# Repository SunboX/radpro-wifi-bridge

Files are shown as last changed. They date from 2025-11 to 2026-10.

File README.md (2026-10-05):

# RadPro WiFi Bridge (ESP32-S3)

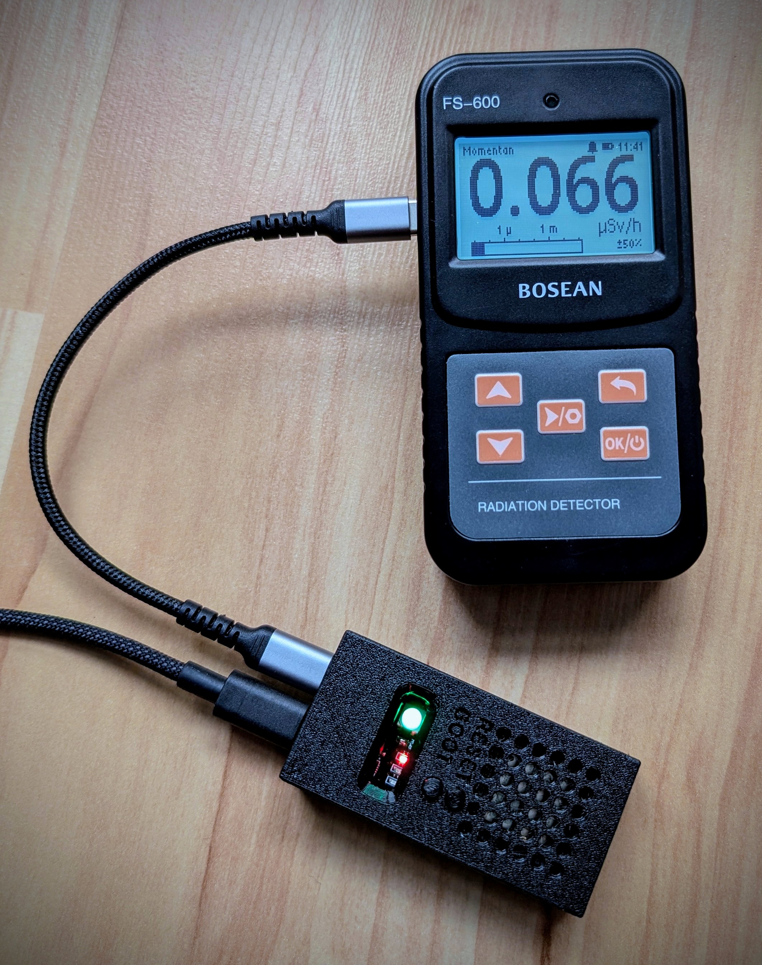
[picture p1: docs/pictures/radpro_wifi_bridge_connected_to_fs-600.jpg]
RadPro WiFi Bridge


Wi-Fi/USB bridge firmware for **Rad Pro class** Geiger counters, built on the excellent open-source Rad Pro firmware from https://github.com/Gissio/radpro.  
The ESP32-S3 enumerates the detector as a vendor-specific CDC device, provides status over the debug UART, keeps a heartbeat on the on-board WS2812, and mirrors telemetry to MQTT plus supported open-data services. Configuration is handled through a captive portal that stays available as a normal web UI once the device is on the network.

**Compatibility note:** Tested with **Bosean FS‑600**, **FNIRSI GC‑01** running firmware **“Rad Pro 3.0.1”** and **“Rad Pro 3.1test17”**, and **FNIRSI GC‑03** running firmware **“Rad Pro 3.1test17”**. Recent GC‑01 units that enumerate as standard STM32 CDC devices are supported as well. If you encounter problems with other adapters, please open an issue so we can track it. I’m happy to help, but I can’t afford to buy every device — get in touch if you’re able to loan or sponsor hardware for debugging.

**Tested Geiger counters**

-   FNIRSI GC-01
-   FNIRSI GC-03
-   Bosean FS-600
-   Bosean FS-5000 (tested by @wern0r)

**Not yet tested**

-   FS2011
-   YT-203B
-   Bosean FS-1000
-   JOY-IT JT-RAD01
-   GQ GMC-800

---

## Highlights

-   **TinyUSB host stack** with a CH34x VCP shim so the RadPro enumerates reliably on the ESP32-S3 OTG port.
-   **DeviceManager command queue** that boots the tube, logs identity/metadata, and keeps issuing telemetry `GET` commands.
-   **Wi-Fi configuration portal** (WiFiManager based) that launches an AP when credentials fail, serves the same form at `http://<device-ip>/`, and persists settings to NVS. A one-click “Restart Device” action is exposed in the UI.
-   **Runtime Wi-Fi diagnostics & startup control**: countdown-driven boot with serial overrides, plus SSID/IP/RSSI logging after the main firmware starts.
-   **MQTT publisher** with templated topics. Every successful RadPro response is forwarded at the configured `readIntervalMs`; publish success/failure drives LED pulses and console messages.
-   **Cloud publishers** for MQTT, OpenSenseMap, OpenRadiation, GMCMap, and Radmon.org with per-service toggles in the web portal.
-   **Home Assistant discovery** payloads so MQTT entities appear automatically once the bridge is online.
-   **Prometheus metrics** at `/metrics` for radiation and battery readings, with device information labels. See [docs/prometheus.md](docs/prometheus.md) for scrape configuration and metric details.
-   **OTA bridge firmware updates** via the web portal (or browser-based ESP Web Tools installer) so you can stay current without reflashing over USB.
-   **RGB LED state machine** (WS2812 on GPIO 48) that communicates boot, Wi-Fi, USB, and error states without needing the serial console.

---

## Hardware Assembly

Need help soldering the ESP32-S3 jumpers or printing the enclosure? Follow the step-by-step guide in [docs/assembly.md](docs/assembly.md). If you are sourcing your own board, see [docs/board-requirements.md](docs/board-requirements.md) for the recommended model and the minimum requirements for the default build.

---

## Board Requirements

The default setup now targets **ESP32-S3-DevKitC-1-N16R8**. The discontinued
**ESP32-S3-DevKitC-1-N16R8V** remains compatible, but it is no longer treated as
the only valid choice.

- **Recommended board:** `ESP32-S3-DevKitC-1-N16R8` (16 MB flash, 8 MB PSRAM, two USB ports, onboard WS2812).
- **Default build requirement:** `16 MB` flash, because the repository ships a dual-OTA layout plus a `2 MB` LittleFS partition.
- **Current firmware requirement:** PSRAM is optional for the current source tree; the default firmware builds without enabling PSRAM-specific support.

See [docs/board-requirements.md](docs/board-requirements.md) if you want to compare alternative boards or port the firmware to a smaller flash layout.

---

## Web Installer (ESP Web Tools)

Flash the bridge firmware straight from your browser: https://SunboX.github.io/radpro-wifi-bridge/web-install/ (v1.15.14)

Connect the ESP32-S3 via USB, click **Install**, and follow the prompts—no local toolchain required. OTA updates of the bridge firmware are also available from the web portal once a network connection is active.

---

## PlatformIO Install

1. Install [PlatformIO](https://platformio.org/) and open this project.
2. The default environment targets the project-local **ESP32-S3 DevKitC-1 (N16R8)** profile with TinyUSB host support (`platformio.ini`) and a custom `partitions.csv` that provides two OTA slots plus a `2 MB` LittleFS partition on `16 MB` flash.
3. Connect the board with **two** USB cables:
    - CP210x (UART) port → logs & commands (`Serial0`, 115200 baud).
    - Native USB-OTG port → leave free for the RadPro sensor.
4. Flash with `platformio run --target upload` (or `--target upload --target monitor` to auto-open the serial monitor).

---

## First Boot & Portal

1. Watch the countdown on the UART. Enter `start` to skip the delay or adjust it with `delay <ms>`.
2. On first boot— or whenever stored credentials fail— the firmware hosts a captive portal named `<device name> Setup`. After Wi-Fi joins successfully the same configuration UI is served at `http://<device-ip>/`.

---

## Wi-Fi Configuration Portal

`WiFiPortalService` keeps the setup UI reachable whether the bridge is broadcasting a captive portal (`<deviceName> Setup`) or already joined to your LAN (`http://<device-ip>/`). Use it to edit Wi-Fi credentials, toggle MQTT/OpenSenseMap/OpenRadiation/Safecast/GMCMap/Radmon publishers, or trigger a remote restart (`/restart`). All changes are persisted to NVS immediately and the console logs SSID/IP/RSSI updates for quick troubleshooting.

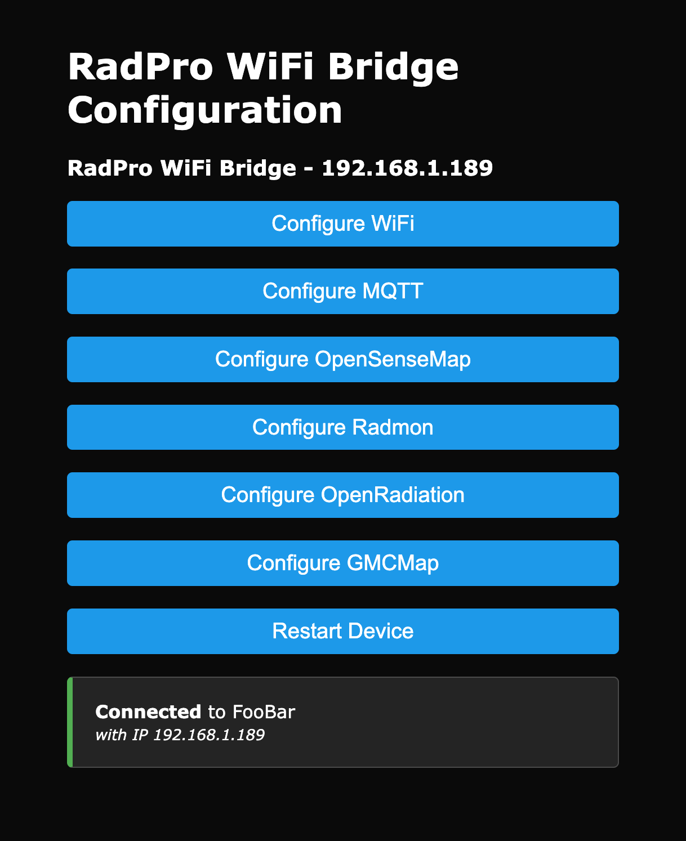
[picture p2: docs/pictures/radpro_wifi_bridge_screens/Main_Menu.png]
Wi-Fi portal Main Menu


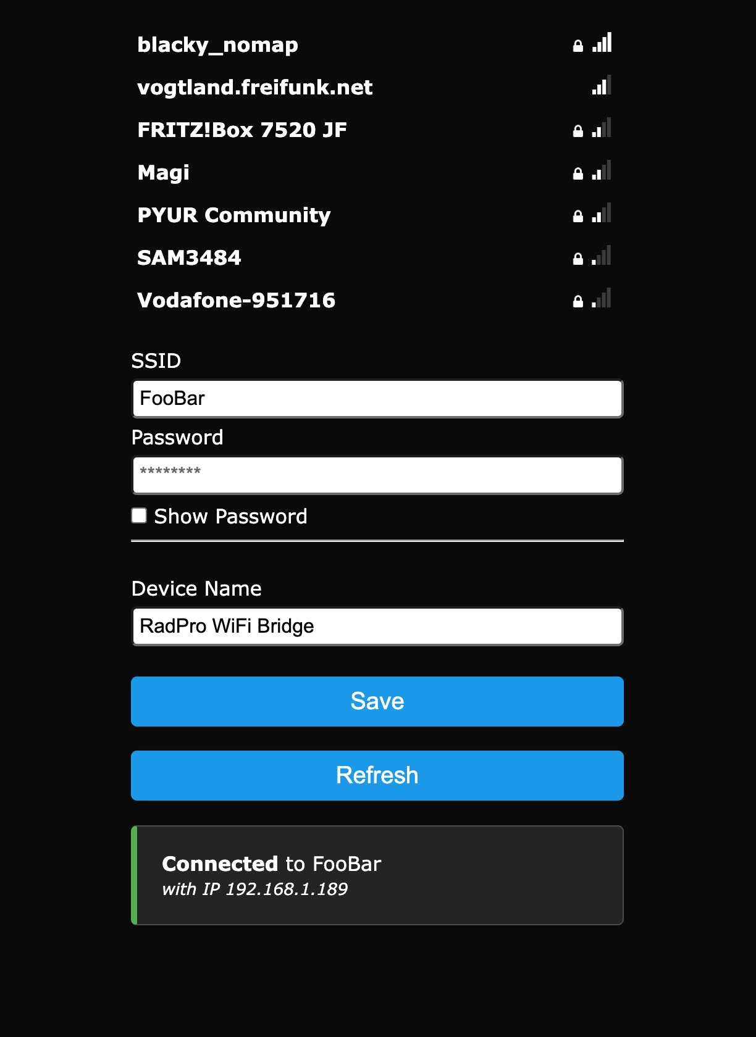
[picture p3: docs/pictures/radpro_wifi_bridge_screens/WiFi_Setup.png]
Wi-Fi setup form


---

## MQTT Publishing

Need a step-by-step walkthrough? See [docs/mqtt-home-assistant.md](docs/mqtt-home-assistant.md) for detailed MQTT broker setup and Home Assistant discovery notes.

The `MqttPublisher` mirrors every RadPro response to MQTT once you enable it in the portal. Topics are templated (`stat/radpro/<deviceid>/<leaf>` by default), retained, and paired with Home Assistant discovery payloads so entities appear automatically. Successful publishes pulse the LED green while the bridge is not in error mode; routine broker outages stay in the console so the bridge can keep showing its healthy USB/Wi-Fi state on the LED. Authentication, configuration, or telemetry alarm states still keep priority on the LED.

---

## OpenSenseMap Publishing

For screenshots and a full walkthrough see [docs/opensensemap.md](docs/opensensemap.md).

Toggle the feature on via **Configure OpenSenseMap**, paste in your box/token/sensor IDs, and the bridge will bundle tube rate + dose rate readings into HTTPS posts every few seconds. Nothing is transmitted while the toggle is off or IDs are blank.

---

## OpenRadiation Publishing

For the setup flow and field-by-field notes see [docs/openradiation.md](docs/openradiation.md).

Enable **Configure OpenRadiation**, enter your API key plus OpenRadiation user ID/password, and fill in the station location metadata used by the OpenRadiation API. The bridge can reuse the connected detector's device ID automatically when the optional apparatus ID is left blank, and the page exposes direct links to the public OpenRadiation map, a redacted dry-run payload preview, and the latest successfully published measurement.

---

## Safecast Publishing

For the full Safecast setup flow and troubleshooting notes see [docs/safecast.md](docs/safecast.md).

Enable **Safecast konfigurieren**, enter your Safecast API key and station coordinates, choose `cpm` or `µSv/h`, and set the upload interval. The bridge posts averaged direct measurements to Safecast, supports one-shot test uploads from the portal, masks the saved API key in the UI, and includes a checkbox plus custom endpoint override for running against a test system instead of production.

---

## GMCMap Publishing

Need screenshots and credentials pointers? See [docs/gmcmap.md](docs/gmcmap.md).

Enable GMCMap support, enter your Account ID/Device ID, and the bridge posts CPM + µSv/h pairs to `log2.asp` roughly once per minute. Leave it disabled if you don’t use GMCMap—no traffic is generated unless credentials are populated.

---

## Radmon Publishing

For screenshots and the full walk-through see [docs/radmon.md](docs/radmon.md).

Enable the Radmon toggle, enter your station username plus data-sending password, and the bridge submits CPM (and µSv/h when available) once per minute. Disable the feature if you don’t use radmon.org; no HTTP requests are made until valid credentials exist.

---

## LED Feedback

Base modes communicate long-running state (default brightness is gentle to avoid glare):

| Mode | Pattern / Colour | Meaning |
| --- | --- | --- |
| `Booting` | Magenta blink (~0.4 s period) | Firmware initialising before the countdown runs. |
| `WaitingForStart` | Yellow blink (~0.6 s period)  | Startup delay active; awaiting timeout or `start` command. |
| `WifiConnecting`  | Blue blink (~0.6 s period) | Attempting to join the configured WLAN. |
| `WifiConnected` | Cyan steady | Wi-Fi joined; USB device not yet ready. |
| `DeviceReady` | Bright green steady | RadPro enumerated and telemetry queue active. |
| `Error` | Amber blink (~0.5 s period) | Device communication or telemetry activity failed; check the console for the current alarm. |

Event pulses temporarily override healthy base colours. Error mode and latched fault patterns keep priority so alarms are not masked:

-   **MQTT success:** bright green flash (~150 ms).
-   **Device command error:** bright red flash (~250 ms) and a console log (`Device command failed: <id>`).
-   **Routine MQTT disconnects:** logged to the console, but they no longer force the LED into the red/amber fault pattern while Wi‑Fi + USB + detector are otherwise healthy.

### Fault Blink Codes

Certain faults latch a repeating red/orange sequence so you can diagnose issues without watching the serial log. The pattern always starts with **one red blink**, followed by the number of **orange blinks** listed below; the sequence then pauses briefly and repeats.

| Code | Issue | LED pattern |
| ---- | --- | --- |
| 1 | NVS load failed (preferences missing) | red ×1 → orange ×1  |
| 2 | NVS write failed (configuration not saved) | red ×1 → orange ×2  |
| 3 | Wi‑Fi authentication / association error | red ×1 → orange ×3  |
| 4 | Wi‑Fi connected but no IP (DHCP/gateway) | red ×1 → orange ×4  |
| 5 | Captive/config portal still required | red ×1 → orange ×5  |
| 6 | MQTT broker unreachable / DNS failure | red ×1 → orange ×6  |
| 7 | MQTT authentication failure | red ×1 → orange ×7  |
| 8 | MQTT connection reset while publishing | red ×1 → orange ×8  |
| 9 | MQTT discovery payload exceeded buffer | red ×1 → orange ×9  |
| 10 | USB device disconnected / CDC error | red ×1 → orange ×10 |
| 11 | USB interface descriptor parse failure | red ×1 → orange ×11 |
| 12 | TinyUSB handshake unsupported | red ×1 → orange ×12 |
| 13 | `GET deviceId` timed out | red ×1 → orange ×13 |
| 14 | Command queue timeout / retries exhausted | red ×1 → orange ×14 |
| 15 | Tube sensitivity missing (dose rate unavailable) | red ×1 → orange ×15 |
| 16 | Wi‑Fi reconnect after config save still failing  | red ×1 → orange ×16 |
| 17 | Captive portal resource exhaustion | red ×1 → orange ×17 |
| 18 | LED controller stuck in Wi‑Fi mode | red ×1 → orange ×18 |
| 19 | Application image larger than partition | red ×1 → orange ×19 |
| 20 | Upload attempted on wrong serial port | red ×1 → orange ×20 |
| 21 | Home Assistant using stale discovery state | red ×1 → orange ×21 |
| 22 | Home Assistant broker without retained discovery | red ×1 → orange ×22 |
| 23 | Last reset caused by brownout | red ×1 → orange ×23 |
| 24 | Last reset caused by watchdog | red ×1 → orange ×24 |

The lowest-numbered active fault is displayed. Resolving the root cause (for example, restoring Wi‑Fi credentials or saving NVS successfully) clears that code and reveals any higher-numbered faults that remain. Some codes are reserved for diagnostic scenarios outside normal runtime, but the blink language stays consistent if you raise them manually.

---

## Serial Console Commands (`Serial0`)

| Command | Description |
| --- | --- |
| `start` | Skip the remaining startup delay and begin immediately. |
| `delay <ms>` | Set a new startup delay (milliseconds) and restart the timer. |
| `raw on/off` | Enable or disable raw USB frame logging. |
| `raw toggle` | Toggle raw USB logging. |

While waiting for the boot delay the console prints `Starting in …` once per second. After the bridge starts, only device data, Wi-Fi status changes, and MQTT diagnostics are logged— the old “Main loop is running.” chatter is gone.

Raw USB logging is invaluable when reverse-engineering RadPro responses; disable it once finished to minimise serial traffic.

---

## Device Telemetry Flow

1. **USB enumeration** uses TinyUSB with a CH34x fallback so the RadPro reliably appears as a CDC device.
2. **Handshake:** `GET deviceId` logs the raw ID, model, firmware, and locale. Additional metadata (`devicePower`, `deviceBatteryVoltage`, `deviceTime`, `tube` parameters) is fetched immediately afterwards.
3. **Continuous polling:** `GET devicePower`, `GET tubePulseCount`, and `GET tubeRate` are queued at the configured interval (`readIntervalMs`, clamped to ≥ 500 ms).
4. **Activity guard:** `devicePower=0`, repeated telemetry timeouts after live data was seen, or a tube pulse counter that stops advancing raises an amber telemetry alarm, clears pending measurement uploads, and suppresses stale tube readings until the detector reports live data again.
5. **MQTT forwarding:** each healthy successful response is offered to the MQTT publisher; failures propagate to the LED and console.
6. **Optional diagnostics:** enable raw USB logging for byte-level traces or request `randomData` / `dataLog` from higher-level code to stream ad-hoc payloads.

Retries, back-off, and duplicate suppression are handled inside `DeviceManager`.

---

## Project Structure

| Path | Purpose |
| --- | --- |
| `src/main.cpp` | Arduino entry point: startup sequencing, Wi-Fi orchestration, LED updates, telemetry loop. |
| `components/usb_host_vcp` | ESP-IDF component that wraps TinyUSB + vendor CH34x handling so the RadPro enumerates reliably. |
| `lib/UsbCdcHost` | High-level USB CDC host wrapper used by `DeviceManager`. |
| `lib/DeviceManager` | Command queue, response parsing, retries/back-off, publish callbacks. |
| `lib/AppSupport/*` | Support modules (AppConfig, ConfigPortal, Mqtt, Led, diagnostics helpers). |
| `docs/assembly.md` | Hardware assembly guide (solder bridges, enclosure, flashing). |
| `docs/mqtt-home-assistant.md` | Detailed MQTT/Home Assistant setup guide. |
| `docs/opensensemap.md`, `docs/openradiation.md`, `docs/safecast.md`, `docs/gmcmap.md`, `docs/radmon.md` | Service-specific publishing guides and setup notes. |
| `docs/web-install/` | Browser-based installer (ESP Web Tools) plus staged firmware bundle (`firmware/latest`). |
| `tools/copy_firmware.py` | PlatformIO post-build hook that refreshes the `docs/web-install/firmware/latest/` artifacts. |
| `platformio.ini` | PlatformIO configuration targeting the ESP32-S3 DevKitC-1 with TinyUSB host support. |

---

## Roadmap

-   Add configurable reporting thresholds / batching beyond the global interval.
-   OTA firmware update of the connected Rad Pro device (bridge already updates itself OTA via the portal).
-   Investigate additional publisher targets:
    -   **uRADMonitor** – global network with proprietary + DIY kits; includes API protocols for feeding third-party data once a device is registered.
    -   **GammaSense** – Waag/RIVM citizen sensing initiative; API access may require project partnership depending on phase/status.

---

## License

This project is available under two licensing options:

### 1. Open-source license

GNU General Public License v3.0 or later (`GPL-3.0-or-later`).

You may use, modify, and distribute this project under the GPL. If you distribute modified versions or larger works based on this project, they must comply with the GPL, including source-code availability requirements.

Documentation, tutorials, diagrams, screenshots, and non-code media are licensed under Creative Commons Attribution-ShareAlike 4.0 (`CC-BY-SA-4.0`) unless otherwise marked.

Case and hardware design files are licensed under the CERN Open Hardware Licence Version 2 - Strongly Reciprocal (`CERN-OHL-S-2.0`) unless otherwise marked.

### 2. Commercial/proprietary license

For use in closed-source, proprietary, or otherwise GPL-incompatible products, a separate commercial license is required.

Commercial licensing contact: **mail@andrefiedler.de**

### Attribution / notices

Copyright (C) 2026 André Fiedler.

Original source: https://github.com/SunboX/radpro-wifi-bridge

Copyright, license, attribution, and source-origin notices must be preserved as required by the GPL and the notice files in this repository.

Bundled third-party components keep their own licenses. See the license files and SPDX metadata within `components/` and `data/portal/js/jszip.min.js` for those terms.

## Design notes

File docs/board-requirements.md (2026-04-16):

# Board Requirements

This project no longer depends on the discontinued
`ESP32-S3-DevKitC-1-N16R8V`. The default PlatformIO profile now targets the
currently common `ESP32-S3-DevKitC-1-N16R8`, and the same firmware layout also
fits `N16R8V` boards.

## Recommended Board

- `ESP32-S3-DevKitC-1-N16R8`
- `16 MB` flash
- `8 MB` PSRAM
- two USB connectors so you can keep the OTG port free for the detector and use
  the second port for flashing/logs
- onboard WS2812 on `GPIO48`

## Minimum Requirements For The Default Build

If you want to compile this repository without changing the partition layout,
your board should provide:

- an `ESP32-S3` with native USB OTG host support
- routing that allows the OTG port to connect to the detector after the
  documented solder bridges are closed
- `16 MB` flash
- a way to flash firmware and read logs while the detector uses the OTG port
  (a second USB/UART path is the easiest option)

## What Is Optional

- PSRAM is currently optional for this firmware. The current codebase builds and
  links without enabling PSRAM-specific support.
- An onboard WS2812 is recommended because the firmware uses it for status, but
  you can adapt the LED wiring if your board exposes a different RGB LED or no
  LED at all.
- The exact DevKitC module suffix is not critical as long as the board meets the
  flash, USB-OTG, and routing requirements.

## If You Want To Use A Smaller Board

Boards with less than `16 MB` flash are not supported by the default layout.
The repository currently reserves:

- two OTA application slots (`ota_0`, `ota_1`)
- a `2 MB` LittleFS partition for the web portal assets

If you want to target an `8 MB` or smaller board, you need to provide your own:

- smaller partition table
- reduced OTA strategy or a single-app layout
- matching web installer offsets if you also want to keep browser flashing

That is possible, but it is a separate board-porting task rather than the
default configuration.

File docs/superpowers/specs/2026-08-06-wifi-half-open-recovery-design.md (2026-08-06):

# Wi-Fi Half-Open Recovery Design

Date: 2026-08-06
Branch: `main`
Target release: `1.15.13`

## Goal

Fix both Wi-Fi recovery failures reported in GitHub issue #21:

- stop the bridge reconnect loop from interrupting a successful station association before DHCP supplies an IP address
- recover when the ESP32 still reports `WL_CONNECTED` although the local Wi-Fi data path is no longer usable

The release will be built and verified locally, but it will be published without a physical-device test because the maintainer is on holiday and currently has no access to the bridge hardware.

## Investigation Summary

The issue contains two distinct failure sequences.

### Rapid reconnect loop

Arduino-ESP32 2.0.17 enables its own automatic reconnect by default. Release 1.15.12 also added an application-level reconnect loop. The bridge sets `pendingReconnect_` on every `STA_DISCONNECTED` event and resets the retry timestamp to zero. After `STA_CONNECTED`, Arduino does not report `WL_CONNECTED` until `GOT_IP`; during that interval the bridge can call `WiFi.reconnect()` again and tear down the association before DHCP completes. The resulting disconnect event resets the retry delay, causing another immediate attempt.

### Beacon-timeout half-open connection

The follow-up log contains `wifi:bcn_timeout,ap_probe_send_start`, followed by repeated MQTT TCP timeouts, but no `STA_DISCONNECTED` event. Espressif documents the beacon timeout as an intermediate state: the station sends probe requests and only disconnects when those probes also fail. In the reported case Arduino continued returning `WL_CONNECTED`, which is also demonstrated by the MQTT publisher proceeding past its Wi-Fi status guard.

The bridge currently arms recovery only after `STA_DISCONNECTED`. It has no independent reachability check, so a stale association can remain offline indefinitely.

The log cannot determine why the original beacons disappeared. Possible causes include RF conditions, temporary AP behavior, or an ESP-IDF 4.4.7 driver state problem. The firmware fix therefore targets reliable recovery rather than claiming to eliminate the initiating radio event.

## Considered Approaches

### 1. Gateway ICMP reachability monitor with a proven-good baseline

Periodically send one asynchronous ICMP echo to the configured gateway. Do not enforce failures until the gateway has answered successfully at least once for the current IP lease. After three consecutive failures, explicitly tear down the stale station connection and hand control to the bridge reconnect state machine.

Advantages:

- tests the local Wi-Fi path independently of MQTT or any internet service
- does not reconnect merely because a configured publisher is unavailable
- the successful-baseline requirement avoids breaking installations whose routers intentionally ignore ICMP

Trade-off:

- recovery begins after a conservative detection window rather than after the first failed packet

### 2. Treat repeated MQTT failures as Wi-Fi failures

This is simpler, but it conflates broker availability, DNS, authentication, and Wi-Fi health. A broker outage could force needless Wi-Fi reconnects, and installations with MQTT disabled would have no watchdog.

### 3. Reboot after prolonged publisher failure

This provides a broad escape hatch but loses diagnostic state, interrupts USB/device processing, and still cannot distinguish a network outage from an application-service outage.

## Selected Approach

Use approach 1 and make the bridge the sole owner of reconnect timing.

- disable Arduino's automatic reconnect after Wi-Fi setup so the Arduino layer and bridge do not issue competing connection commands
- suppress application reconnect attempts while association is waiting for `GOT_IP`
- preserve the retry timestamp across repeated disconnect callbacks instead of making every callback immediately due
- clear reconnect state explicitly on `GOT_IP`
- monitor the gateway with asynchronous, single-packet ICMP probes
- require one successful gateway probe before enforcing failures for the current IP lease
- recover after three consecutive failed probes

## Detailed Design

### Reconnect state policy

Extend the existing host-testable Wi-Fi reconnect policy with pure decisions for:

- whether a reconnect attempt must wait while DHCP is in progress
- whether a new disconnect should make the first retry immediately due or preserve an already-running retry interval
- when a gateway failure streak becomes actionable

Runtime behavior:

1. `STA_DISCONNECTED` arms reconnect immediately only when reconnect was not already pending.
2. `STA_CONNECTED` records the start of the DHCP wait and prevents another reconnect attempt.
3. `GOT_IP` clears `pendingReconnect_`, the retry timestamp, and the DHCP wait.
4. If `GOT_IP` does not arrive within ten seconds, DHCP waiting expires and the normal five-second reconnect policy resumes.
5. Arduino auto-reconnect is disabled so only this state machine issues reconnect requests.

### Gateway health policy

Add a small host-testable policy object with these states:

- `unproven`: no successful gateway response has been observed for the current lease
- `healthy`: at least one response has been observed and the failure streak is zero
- `suspect`: the gateway was previously proven reachable and one or two consecutive probes failed
- `stale`: the gateway was previously proven reachable and three consecutive probes failed

Rules:

- a success proves the gateway and resets the failure streak
- failures before the first success are diagnostic only and never force recovery
- three consecutive failures after a success request stale-link recovery
- a new IP lease resets the policy to `unproven`
- any Wi-Fi disconnect cancels enforcement until a new `GOT_IP`

### Gateway probe runtime

Use ESP-IDF's asynchronous `esp_ping` session API:

- target: `WiFi.gatewayIP()`
- packet count: one
- timeout: 1000 ms
- interval between probes: 30 seconds
- no blocking work in the Arduino loop

The ping callbacks only record completion and success. The main loop consumes the result, updates the pure policy, and performs all logging and Wi-Fi state changes.

If the ping session cannot be created or started, log the ESP error and retry at the next interval. Session-setup errors do not count as gateway failures.

When the policy reports a stale link:

1. log the failure count and gateway address
2. stop treating the cached `WL_CONNECTED` value as healthy
3. arm bridge reconnect state
4. explicitly disconnect the station without erasing saved credentials
5. let the normal reconnect policy rejoin the saved network

### Logging and diagnostics

Add concise state-transition logs rather than one line for every successful periodic probe:

- gateway monitor armed after its first successful probe
- gateway probe failure count while armed
- stale link detected and forced recovery started
- DHCP wait timed out
- ping session creation/start failure with the ESP error name

Successful probes after the baseline remain silent unless they recover a prior failure streak.

## Error Handling and Safety

- Router does not answer ICMP: the monitor never gets a successful baseline and therefore never forces recovery.
- Gateway address is zero or unavailable: skip probing until a valid `GOT_IP` event supplies one.
- Ping allocation/socket failure: log and retry later; do not classify the link as stale.
- Wi-Fi disconnect during a probe: ignore the completed result for health enforcement and reset on the next IP lease.
- DHCP is slow: wait up to ten seconds before allowing another reconnect command.
- Gateway recovers after one or two missed probes: reset the failure streak without disconnecting Wi-Fi.
- Persistent gateway failure after a proven-good baseline: force one disconnect, reset health state, and rely on the existing bounded reconnect interval.
- Saved credentials remain intact throughout recovery.

## Testing

Follow a red-green test cycle before implementation.

Host regression tests will cover:

- reconnect is suppressed between `STA_CONNECTED` and `GOT_IP`
- DHCP waiting expires after ten seconds
- repeated disconnect callbacks preserve an active retry delay
- `GOT_IP` clears pending reconnect state
- gateway failures before the first success never trigger recovery
- a success arms gateway enforcement
- one and two post-baseline failures remain non-actionable
- the third consecutive post-baseline failure triggers stale-link recovery
- a success resets a failure streak
- a new lease resets the successful baseline

Build verification will include:

- all repository host tests
- PlatformIO `buildprog`
- PlatformIO `buildfs`
- inspection of generated version metadata and the `firmware_1.15.13.zip` contents
- comparison of the committed source state with the generated firmware version string

Physical-device behavior will remain explicitly unverified for this release because no device is available during the maintainer's holiday.

## Release and Issue Communication

Release 1.15.13 will include:

- a detailed explanation of the two failure modes
- the gateway-monitor design and false-positive protection
- the reconnect/DHCP race correction
- local test and build evidence
- a clear statement that the release has not yet been tested on physical hardware

The GitHub issue reply will be written as a short, direct maintainer update in André's established style: thank the reporter, explain the investigation and fix in concrete terms, link the release, state that hardware testing was not possible while on holiday, and ask the reporter to test and share a log if possible.

## Non-Goals

- claiming the firmware can identify the original RF or access-point cause from the supplied log
- treating cloud-service or MQTT outages as Wi-Fi failures
- restarting the whole ESP32 as the first recovery action
- erasing or replacing stored Wi-Fi credentials
- upgrading the Arduino-ESP32 or ESP-IDF toolchain in the same release

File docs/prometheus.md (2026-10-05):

# Prometheus metrics

The bridge exposes its current detector readings at `http://<device-ip>/metrics`
on the same HTTP server as the web portal. Prometheus can scrape this endpoint
without MQTT or a separate exporter, and Grafana can display the stored readings
through a Prometheus data source.

Add a scrape job to `prometheus.yml`, replacing the example IP with your bridge:

```yaml
scrape_configs:
  - job_name: radpro
    scrape_interval: 15s
    static_configs:
      - targets: ["192.168.1.50:80"]
```

The default Prometheus metrics path is `/metrics`.

| Metric | Type | Unit / meaning |
| --- | --- | --- |
| `radpro_info` | Gauge | Constant `1`, with manufacturer, model, detector firmware, bridge firmware, device ID, locale and device power labels |
| `radpro_tube_rate` | Gauge | Counts per minute |
| `radpro_tube_dose_rate` | Gauge | Microsieverts per hour |
| `radpro_tube_pulse_count` | Counter | Detector pulse count; can reset when the detector resets |
| `radpro_battery_voltage` | Gauge | Volts |
| `radpro_battery_percent` | Gauge | Battery percentage estimated by the bridge from battery voltage |

The endpoint exports the latest readings already collected by the bridge.
Scraping it does not trigger a detector read. Unavailable readings are omitted,
including during startup, after USB disconnect, or while measurements are
cleared because the detector is off or stale. A missing sensitivity may leave
the dose-rate metric unavailable while CPM remains available. Actual zero
readings are exported as zero.

Device labels support UTF-8. Backslashes, double quotes and line feeds are escaped
according to the Prometheus text format.

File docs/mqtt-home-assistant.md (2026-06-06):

# MQTT & Home Assistant Integration

This guide walks through configuring the RadPro WiFi Bridge to publish RadPro telemetry over MQTT and explains how Home Assistant automatically discovers the exposed entities.

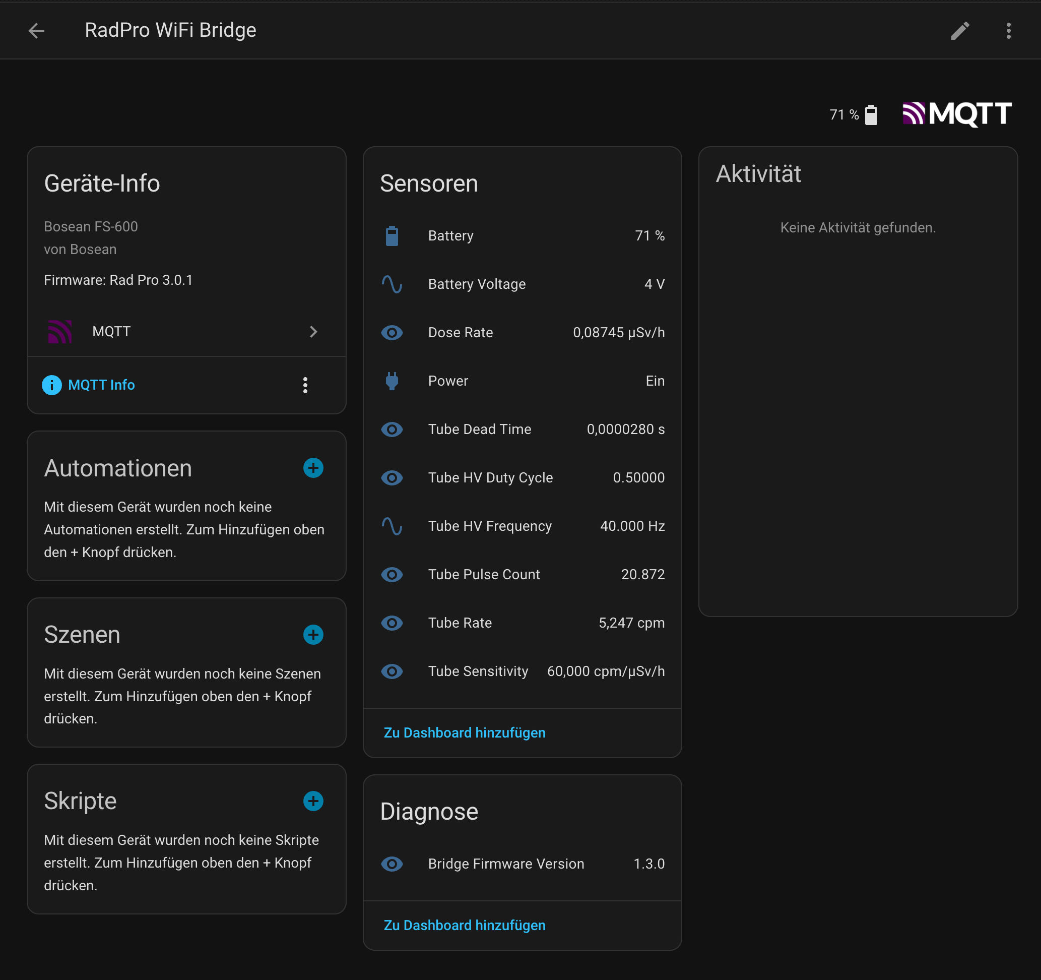
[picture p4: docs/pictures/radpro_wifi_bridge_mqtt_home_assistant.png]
RadPro WiFi Bridge sensors rendered inside Home Assistant


## 1. Prepare Your MQTT Broker

1. Run an MQTT broker such as Mosquitto (Home Assistant add-on or stand-alone).
2. Create a dedicated MQTT user/password, or enable anonymous access:
   - **Home Assistant add-on:** set `anonymous: true` under the add-on options, *or* add a user in Home Assistant and grant MQTT access.
3. Note the broker host/IP and port (default 1883).

> **Tip:** A `MQTT connect failed: 5` log on the bridge means the broker rejected the credentials. `MQTT connect failed: -1` or `-2` usually means the bridge cannot open the TCP connection to the broker.

## 2. Configure MQTT in the Portal

1. Power the bridge and connect via Wi-Fi/Captive portal.
2. Open **Configure MQTT**:
   - Toggle **Enable MQTT publishing**.
   - Fill in host, port, client ID suffix, username/password.
   - Adjust the base topic (`mqttTopic`) and full topic template (`mqttFullTopic`) if you want to customise the namespace. Defaults yield `stat/radpro/<deviceid>/<leaf>`.
   - Set the RadPro polling interval (`readIntervalMs`, minimum 500 ms).
3. Save to write the settings to NVS; the bridge will reconnect with the new details.

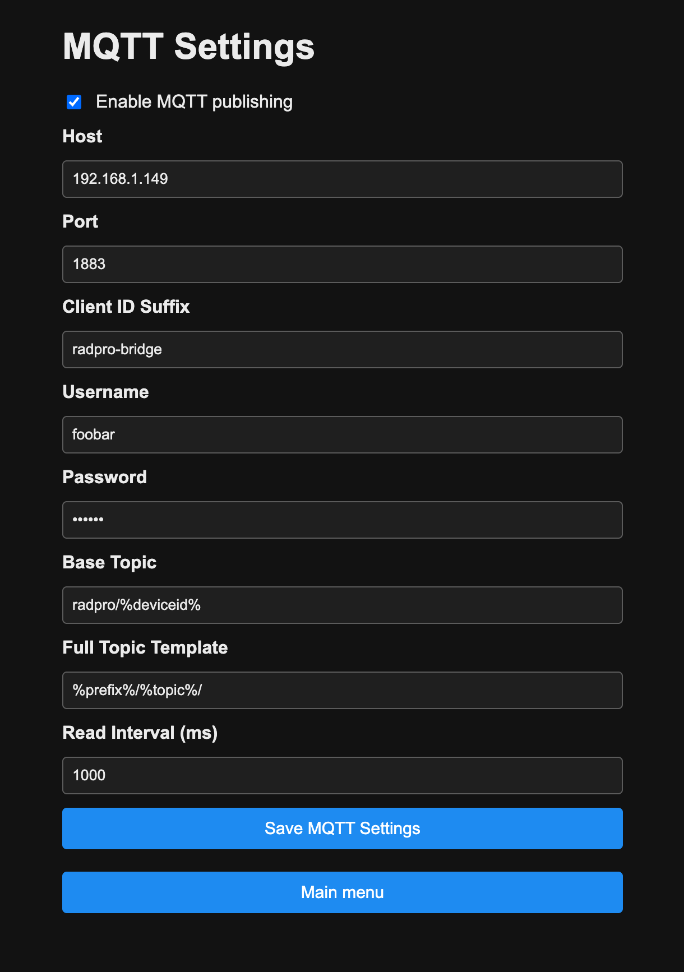
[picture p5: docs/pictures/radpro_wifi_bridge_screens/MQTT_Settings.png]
MQTT configuration page


## 3. Published Topics

Once connected, every RadPro response is forwarded to MQTT. The bridge publishes (retained) leaves such as:

- `bridgeVersion`, `deviceId`, `devicePower`
- `deviceBatteryVoltage`, `deviceBatteryPercent`
- `tubePulseCount`, `tubeRate`, `tubeDoseRate`, `tubeDeadTime`, `tubeDeadTimeCompensation`
- `tubeHvFrequency`, `tubeHvDutyCycle`
- Diagnostic entries like `randomData` or `dataLog` (not retained)

Topic templating variables:

- `%deviceid%` → lower-case slug of the RadPro device ID.
- `%DeviceId%` → exact device ID.
- `%prefix%` and `%topic%` → inserted into the full topic template to build the final MQTT topic string.

## 4. Home Assistant Discovery

As soon as the bridge learns the RadPro device ID it emits MQTT Discovery payloads under `homeassistant/<component>/<unique_id>/config`. Home Assistant automatically creates entities for:

- Tube rate (cpm) sensor
- Tube dose-rate sensor
- Pulse count
- Battery voltage & percentage
- Device power state
- Bridge firmware/diagnostics

Entities update in place whenever you rename the device in the portal or change topics. To ensure Home Assistant keeps the discovery data:

- Keep MQTT retain enabled (default behaviour on the bridge).
- If you purge retained messages manually, restart the bridge afterward to republish discovery payloads.

### Fixing Missing Entities

If Home Assistant doesn’t show the entities:

1. Confirm the bridge is publishing to the broker (`mosquitto_sub -v -t 'homeassistant/#'`).
2. Ensure the Home Assistant broker has `retain` enabled and that discovery is turned on (`mqtt:` in `configuration.yaml`).
3. Clear stale discovery topics:
   - Delete `homeassistant/radpro_*` retained topics (e.g. via MQTT Explorer).
   - Restart the bridge so it re-sends discovery payloads.

## 5. Using the Data

Once entities appear, you can:

- Display tube rate / dose rate in Lovelace dashboards.
- Trigger automations (e.g., notification if dose rate exceeds a threshold).
- Record long-term statistics using Home Assistant’s Recorder/History.

## Troubleshooting Checklist

| Symptom | Fix |
| --- | --- |
| `MQTT connect failed: -1` or `-2` | Broker unreachable (check host, port, Wi-Fi, firewall rules, VLAN/routing, and Home Assistant add-on network access) |
| `MQTT connect failed: 5` | Bad username/password or anonymous disabled |
| Entities missing after rename | Clear retained `homeassistant/` topics and restart bridge |
| State updates delayed | Lower `readIntervalMs` (>= 500 ms) and ensure broker isn’t rate-limited |

If a desktop MQTT client can connect but the bridge still logs `-1` or `-2`, test from the same Wi-Fi/VLAN as the bridge and check that no firewall rule blocks traffic from the bridge IP to the broker port.

For more detail on the firmware internals, see the “MQTT Publishing” section in the root README.

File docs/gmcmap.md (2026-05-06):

# GMCMap Publishing

This guide explains how to configure the RadPro WiFi Bridge to submit readings to [GMCMap](https://www.gmcmap.com/).

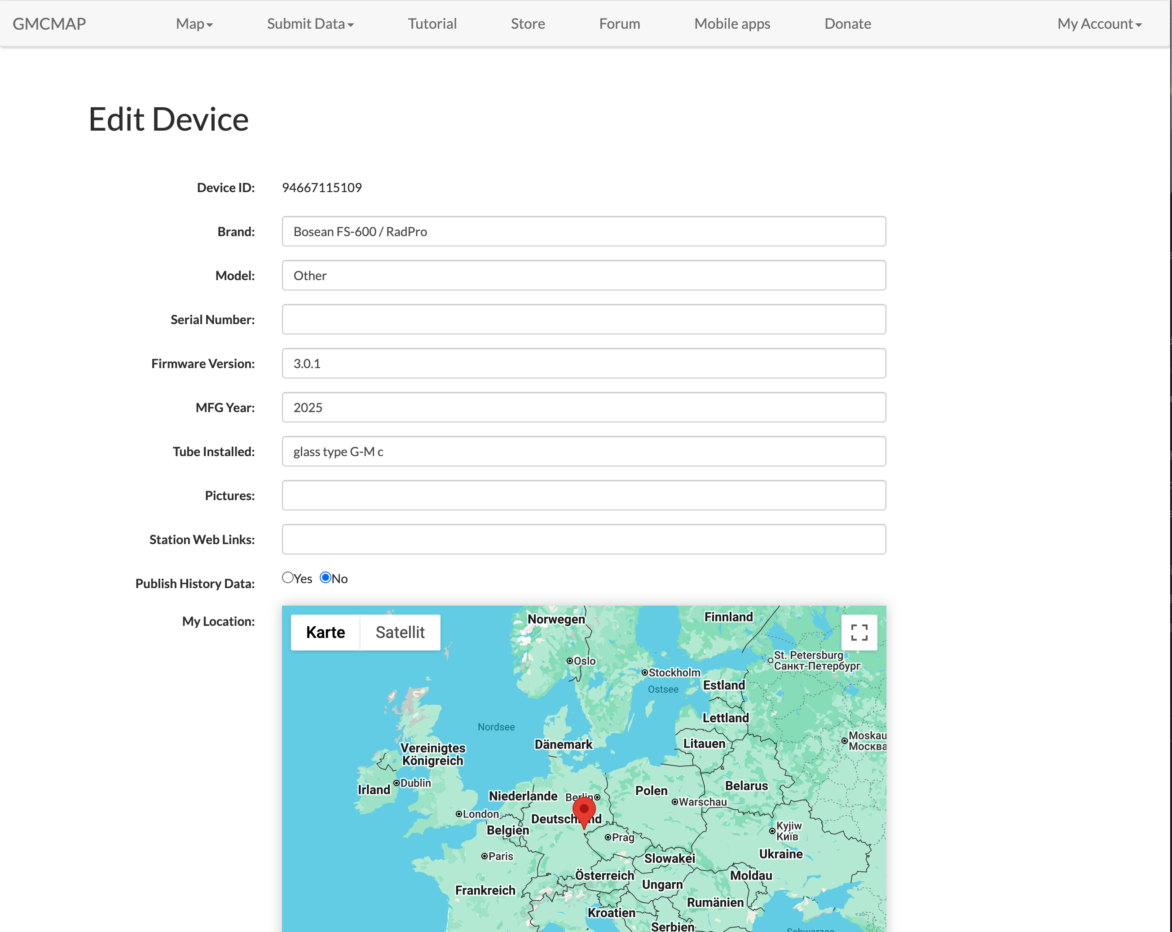
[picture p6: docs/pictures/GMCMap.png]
GMCMap dashboard with RadPro WiFi Bridge device


## 1. Get Your GMCMap Credentials

1. Log in to GMCMap and open **My Account** → **My Geiger Counter**.
2. For the device you want to feed with the bridge, note:
   - **Account ID** (a numeric identifier).
   - **Device ID** (also numeric, unique per counter).
   - Optional **Password** (only if you set one—leave blank otherwise).

These values appear on the device details page and are needed in the bridge portal.

## 2. Configure the RadPro WiFi Bridge

1. Open the Wi-Fi portal and go to **Configure GMCMap**.
2. Tick **Enable GMCMap publishing**.
3. Enter:
   - **Account ID** – from the GMCMap dashboard.
   - **Device ID** – the device you want to report measurements for.
4. Save the form; credentials are stored in NVS immediately.
5. After saving, the settings page shows a direct link to the device history page on GMCMap.

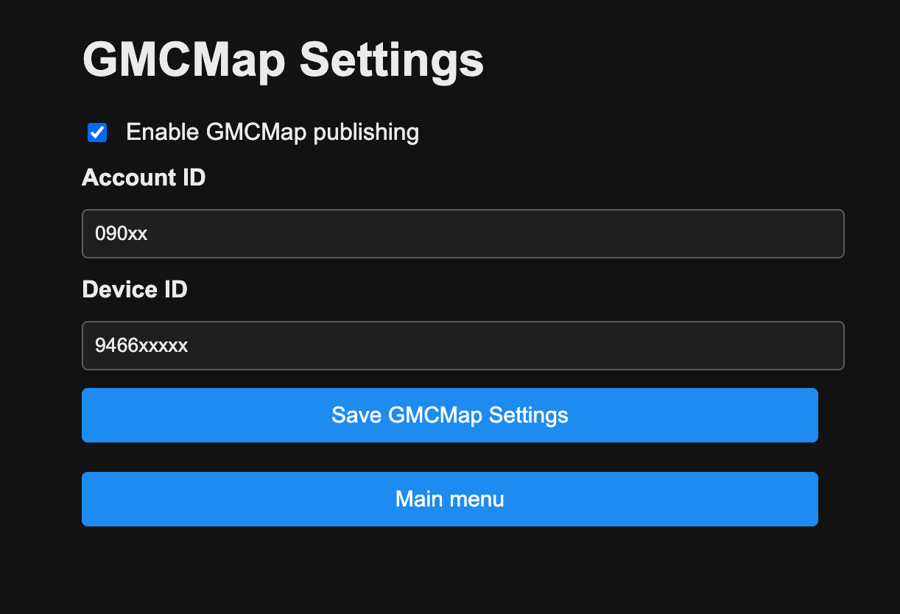
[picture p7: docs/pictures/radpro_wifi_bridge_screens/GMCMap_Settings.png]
Portal GMCMap configuration page


## 3. Publishing Behaviour

- The bridge waits until it has both tube rate (CPM) and dose rate (µSv/h) readings.
- It sends a single HTTP GET request to `https://www.gmcmap.com/log2.asp` with:
  - `AID=<Account ID>`
  - `GID=<Device ID>`
  - `CPM=<tube rate rounded to the nearest whole CPM>`
  - `ACPM=<averaged tube rate rounded to the nearest whole CPM>`
  - `uSV=<dose rate>`
- Requests are throttled to roughly once per minute to respect GMCMap’s API guidelines.

## 4. Verifying Data

- On the bridge serial console, look for `GMCMap: GET ...` entries confirming submissions.
- In GMCMap, open **Recent Data** or the device page to see CPM/µSv/h entries from the bridge.

## Troubleshooting

| Symptom | Fix |
| --- | --- |
| HTTP 403/`GID invalid` | Device ID doesn’t exist or doesn’t belong to the provided Account ID. Double-check both values. |
| HTTP 400 | Missing parameters—ensure CPM and µSv/h readings are available and IDs are filled in. |
| No data in dashboard | Give the bridge a minute between submissions; verify the device password (if any) matches GMCMap’s record. |

Disable the feature if you are not using GMCMap; no HTTP traffic is generated unless the toggle is on and valid IDs are configured. \ No newline at end of file

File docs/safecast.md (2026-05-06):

# Safecast Publishing

This guide explains how to connect the RadPro WiFi Bridge to [Safecast](https://safecast.org/) and how the bridge's Safecast upload mode behaves.

## 1. Prepare Your Safecast Account

1. Create a Safecast account at [api.safecast.org/en-US/users/sign_up](https://api.safecast.org/en-US/users/sign_up) or log into an existing one.
2. Open your Safecast profile and copy your API key.
3. Decide whether you want to provide a **Device ID**:
   - Leave it blank if you only want to send the minimum required measurement fields.
   - Fill it in if you already created a Safecast device for this station and want uploads tied to that device record.
4. Decide which unit you want the bridge to publish:
   - `cpm` for count rate uploads.
   - `µSv/h` if your detector already reports dose rate and you want the bridge to send Safecast's internal `usv` unit value.

## 2. Configure the RadPro WiFi Bridge

1. Open the Wi-Fi portal and go to **Safecast konfigurieren**.
2. Tick **Enable Safecast publishing**.
3. Enter:
   - **API Endpoint** - normally `https://api.safecast.org`.
   - **API Key** - your Safecast API key from the profile page.
   - **Device ID** - optional numeric Safecast device ID.
   - **Latitude / Longitude** - station coordinates in decimal degrees.
   - **Height Above Ground (cm)** - optional sensor height relative to the local ground.
   - **Location Name / Label** - optional human-readable station label.
   - **Unit** - `cpm` or `µSv/h`.
   - **Upload Interval (seconds)** - minimum `60`, default `300`.
4. Optional advanced settings:
   - **Use development / test endpoint** - switches from the normal production host to the documented Safecast test host.
   - **Custom endpoint override** - use this if you want to point the bridge at a different Safecast-compatible host.
   - **Enable HTTP debug logging** - logs the redacted request URL, payload, status code, and response body to the serial console.
5. Save the form. Settings are written to NVS immediately.

The portal masks the stored API key when you reopen the page. Leave the API key field blank when editing other settings if you want to keep the saved key unchanged.

## Open Data Note

Safecast is an open-data platform. When you enable the integration, uploaded measurements, timestamps, and location data may become publicly visible and may be reused as open data.

Enable the feature only if you are comfortable with publishing that station metadata.

## 3. Test the Configuration

Use **Send Test Upload** before enabling unattended publishing for a station you care about.

- The bridge validates the current form values first.
- It uses the latest detector reading for the selected unit.
- It submits one measurement immediately.
- The page shows the HTTP status code and the response body.
- The test action does not save the form unless you also press **Save Safecast Settings**.

If the detector has not produced a reading for the chosen unit yet, the test upload will fail locally and no request is sent.

## 4. Publishing Behaviour

- The bridge publishes direct measurements to `POST /measurements.json`.
- Authentication is sent as `?api_key=<your key>` on the request URL.
- Payloads are JSON and include:
  - `latitude`
  - `longitude`
  - `value`
  - `unit`
  - `captured_at`
  - optional `device_id`
  - optional `height`
  - optional `location_name`
- Timestamps are generated in UTC ISO-8601 format.
- Automatic uploads are averaged over the configured upload interval instead of sending every detector tick.
- Negative or invalid detector values are ignored.
- The bridge keeps separate sample windows for CPM and dose rate, then chooses the correct one based on the configured Safecast unit.

### Unit Handling

- `cpm` in the portal is sent to Safecast as `cpm`.
- `µSv/h` in the portal is sent to Safecast as `usv`.
- The bridge does not invent a CPM-to-dose conversion. If you choose `µSv/h`, the detector must already provide a valid dose-rate reading.

## 5. Verify Data

- Watch the serial console for `Safecast: POST ...` messages or HTTP status logs.
- Use the bridge portal's test-upload result to confirm that Safecast accepts the current configuration.
- Check the public Safecast data view at [safecast.org/data](https://safecast.org/data/) after a successful production upload.

Safecast visibility may depend on their backend processing and the way the upload is associated with your account or device.

## Security Notes

- The bridge stores the Safecast API key in on-device NVS, not in the repository.
- The portal masks saved API keys when rendering the form.
- Serial logs redact the `api_key` query parameter before printing request URLs.
- Treat `/backup.json` exports as sensitive because they include saved service credentials.

## Troubleshooting

| Symptom | Fix |
| --- | --- |
| `Safecast API key is required.` | Enter the API key and save again, or provide it in the test-upload form before testing. |
| `Latitude must be between -90 and 90.` or `Longitude must be between -180 and 180.` | Correct the station coordinates and save again. |
| `Upload interval must be at least 60 seconds.` | Raise the interval to `60` or more. |
| `No current detector reading is available for the selected unit.` | Wait for the detector to report CPM or dose rate for the chosen unit, then retry. |
| `Safecast: connect failed.` | Check Wi-Fi/DNS reachability and confirm the selected endpoint host is valid. |
| HTTP `401` or `403` | Re-check the API key and confirm the account is allowed to upload. |
| HTTP `404` | The endpoint URL is wrong. Use the default API host or a correct custom override. |
| HTTP `422` | Safecast rejected the payload fields. Re-check unit, coordinates, and optional numeric values such as device ID or height. |

If the documented Safecast development host is unavailable, leave **Use development / test endpoint** disabled and point **Custom endpoint override** at the test system you actually want to use.

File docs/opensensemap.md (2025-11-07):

# OpenSenseMap Integration

This walkthrough covers creating a senseBox, collecting the required IDs, and configuring the RadPro WiFi Bridge so tube rate and dose rate are forwarded to [openSenseMap](https://opensensemap.org/).

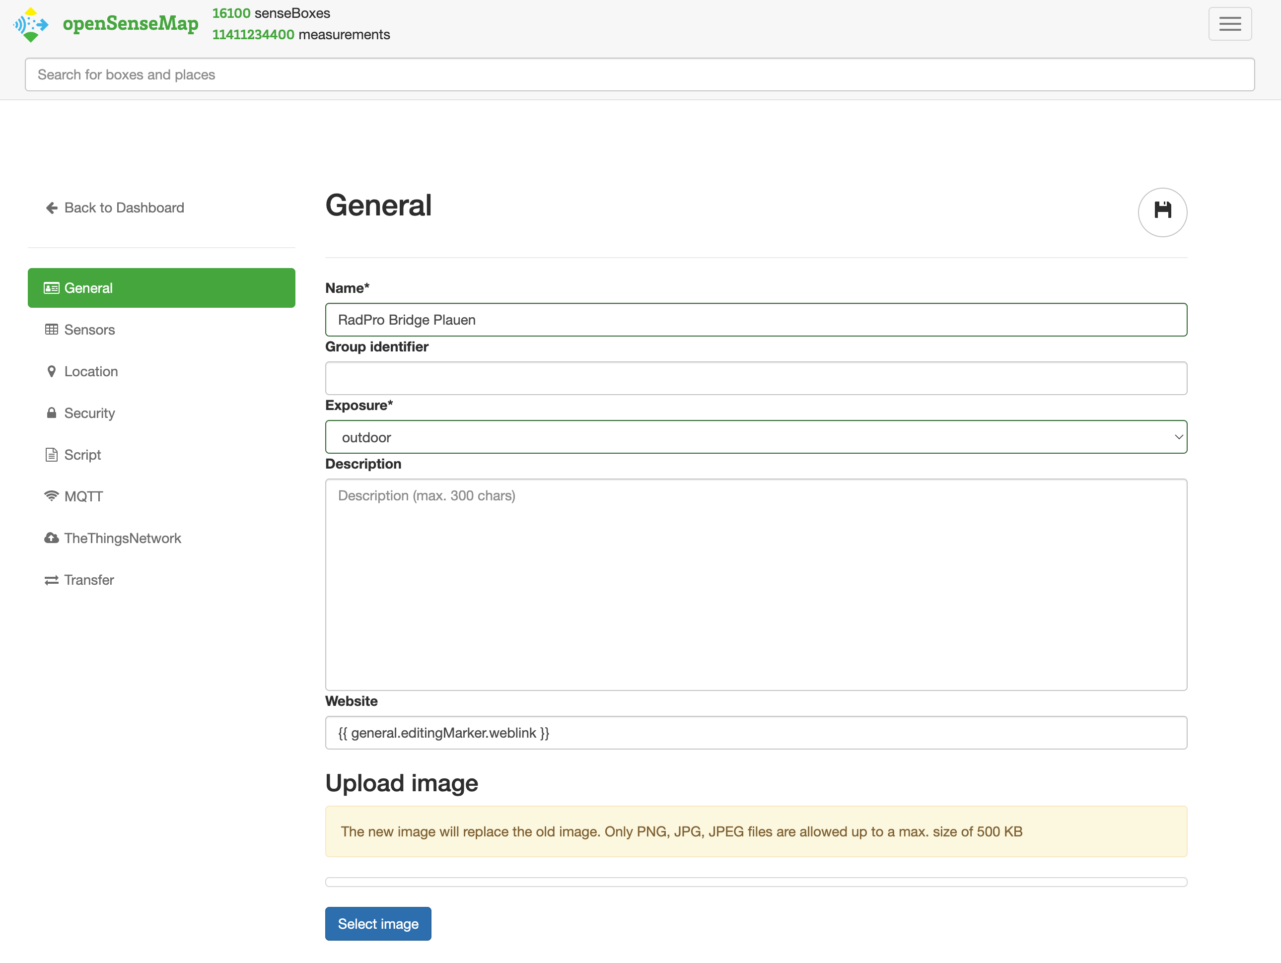
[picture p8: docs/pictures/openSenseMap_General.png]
Example senseBox summary showing IDs and sensors


## 1. Create or Prepare Your senseBox

1. Log in to openSenseMap and choose **Create a senseBox** (or edit an existing one dedicated to RadPro data).
2. Fill in:
   - **Station name** and **description** (e.g., “RadPro WiFi Bridge”).
   - **Exposure** (indoor/outdoor/mobile) to match the installation.
   - Location (drag the map marker or enter coordinates).
3. Under **Hardware**, select **Manual configuration**.
4. Add two sensors:
   - **Tube Rate (cpm)** – Unit `cpm`, type “RadPro FS-600 Geiger” (or any Geiger count rate type).
   - **Dose Rate (µSv/h)** – Unit `µSv/h`, type “RadPro FS-600 Dose” (or any dose-rate type).
5. Save the box; the confirmation screen lists the **senseBox ID**, **Access Token**, and each sensor’s `_id`.

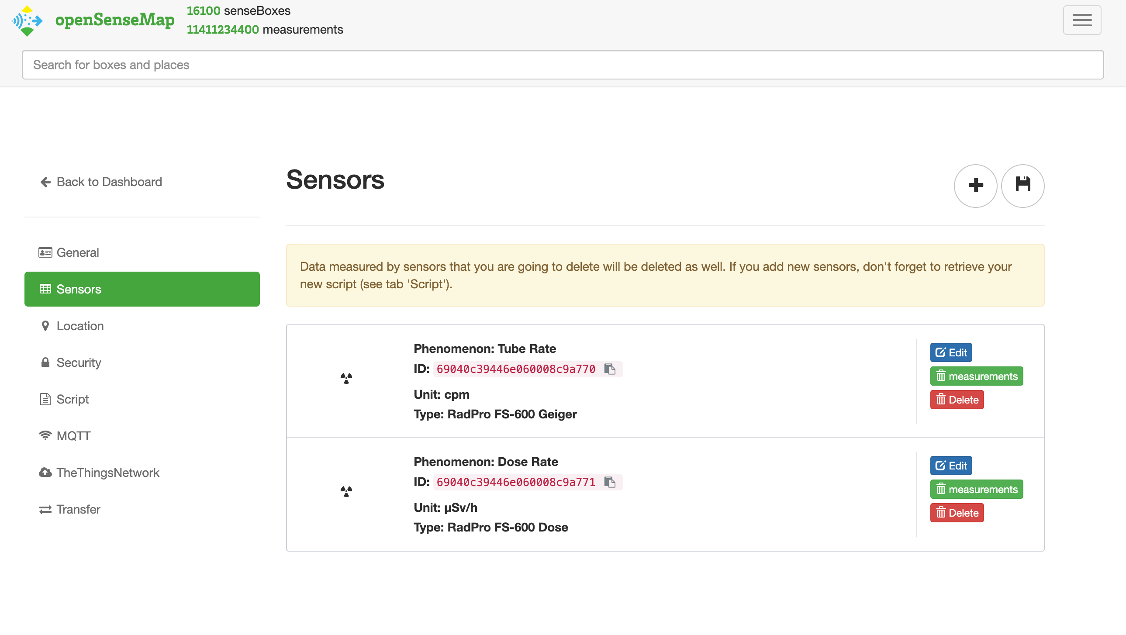
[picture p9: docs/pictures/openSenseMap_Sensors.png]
Equipment tab showing sensor IDs for tube rate and dose rate


## 2. Grab the Required IDs

You need four values for the RadPro bridge:

| Field | Where to find it |
| --- | --- |
| senseBox ID | Summary page after saving the box, or `My senseBoxes` → select box → **General** |
| Access Token (API key) | Same summary page (`Access Token`), also under **Edit box** → **General** |
| Tube rate sensor `_id` | `My senseBoxes` → pick box → **Equipment** tab (copy the ID next to the tube rate sensor) |
| Dose rate sensor `_id` | Same page, ID next to the dose rate sensor |

> Alternative: `GET https://api.opensensemap.org/boxes/<senseBoxId>` returns JSON; copy the `_id` values from the `sensors` array.

## 3. Configure the RadPro WiFi Bridge

1. Open the bridge portal and select **Configure OpenSenseMap**.
2. Tick **Enable OpenSenseMap publishing**.
3. Enter:
   - **Box ID** → senseBox ID.
   - **Access Token** → API key.
   - **Tube Rate Sensor ID** → `_id` of the CPM sensor.
   - **Dose Rate Sensor ID** → `_id` of the µSv/h sensor.
4. Save the form; settings are stored in NVS.

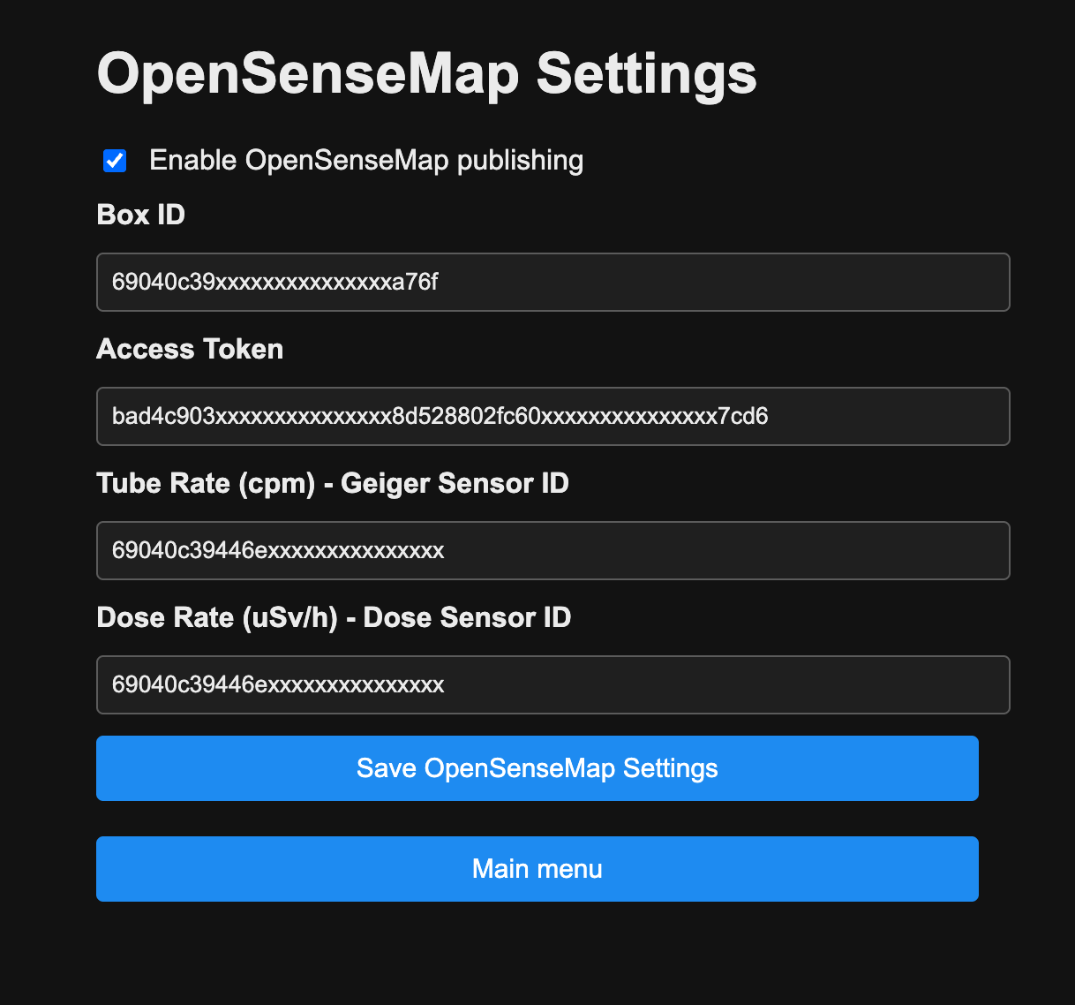
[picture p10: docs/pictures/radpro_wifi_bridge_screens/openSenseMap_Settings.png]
Portal OpenSenseMap configuration page


### How the Bridge Publishes

- Tube rate and dose rate are queued until both are available, then sent together via HTTPS (about every 4 s) to stay within openSenseMap’s API limits.
- Wi-Fi/API failures trigger retries with a short back-off; nothing is sent while the feature is disabled or IDs are missing.

## 4. Verify Data Flow

- In openSenseMap, open your senseBox and check the **Measurements** view for incoming CPM/µSv/h points.
- Use the bridge serial console to confirm transmissions (look for `OpenSenseMap: POST tube=...` lines) or enable the raw USB logs if troubleshooting.

## Troubleshooting

| Issue | Fix |
| --- | --- |
| `OpenSenseMap: connect failed` | Wi-Fi or DNS issue; verify network connectivity. |
| HTTP 4xx/5xx errors | Re-check Box ID, API key, sensor IDs; ensure the Access Token hasn’t been revoked. |
| No data in graph | Make sure both sensor IDs are set— tube and dose are uploaded together. |

Need to change sensor naming or add extra metadata? You can edit the senseBox at any time; just keep the sensor IDs in sync with the bridge configuration. \ No newline at end of file

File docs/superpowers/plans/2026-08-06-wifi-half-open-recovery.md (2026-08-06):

# Wi-Fi Half-Open Recovery Implementation Plan

> **For agentic workers:** REQUIRED SUB-SKILL: Use superpowers:executing-plans to implement this plan task-by-task. Steps use checkbox (`- [ ]`) syntax for tracking.

**Goal:** Fix the reconnect/DHCP race and recover from a stale `WL_CONNECTED` state by releasing firmware 1.15.13 with a conservative gateway-reachability monitor.

**Architecture:** Keep timing and health decisions in the existing host-testable reconnect policy. Make `WiFiPortalService` the sole owner of station reconnection, protect the DHCP interval after association, and use ESP-IDF's asynchronous ping API to prove and monitor gateway reachability without coupling Wi-Fi recovery to MQTT.

**Tech Stack:** C++17, Arduino-ESP32 2.0.17, ESP-IDF 4.4.7, PlatformIO, ESP-IDF `esp_ping`, host-side C++ tests, GitHub CLI.

---

## File Structure

- Modify: `lib/AppSupport/ConfigPortal/WiFiReconnectPolicy.h`
  - Add pure DHCP-in-flight, disconnect retry, and gateway health policy helpers.
- Modify: `test/host/wifi_reconnect_policy_test.cpp`
  - Cover the two reported recovery failures and gateway false-positive protection.
- Modify: `lib/AppSupport/ConfigPortal/WiFiPortalService.h`
  - Add asynchronous gateway-probe state and callback declarations.
- Modify: `lib/AppSupport/ConfigPortal/WiFiPortalService.cpp`
  - Disable competing Arduino auto-reconnect, protect DHCP progress, and run the gateway monitor.
- Create: `version.txt`
  - Pin the ESP-IDF application descriptor to the release version.
- Modify: `platformio.ini`, `README.md`, `docs/web-install/manifest.json`
  - Bump user-facing release metadata to 1.15.13.
- Create: `docs/web-install/firmware/firmware_1.15.13.zip`
  - Package the freshly built application and LittleFS images.

### Task 1: Extend The Host-Tested Reconnect Policy

- [ ] Add failing tests for the ten-second DHCP guard and first-versus-repeated disconnect retry state.
- [ ] Add failing tests for unproven gateways, arming on success, three post-baseline failures, recovery, and lease reset.
- [ ] Compile the test and confirm it fails because the new policy API does not exist.
- [ ] Implement the minimal pure policy helpers.
- [ ] Recompile and confirm the complete reconnect policy test passes.

### Task 2: Integrate The Runtime Reconnect Fix

- [ ] Disable WiFiManager and Arduino automatic reconnect so the bridge owns reconnect timing.
- [ ] Treat `STA_CONNECTED` and an explicit reconnect command as an in-flight DHCP interval.
- [ ] Preserve retry timing across repeated `STA_DISCONNECTED` callbacks.
- [ ] Clear reconnect state only on `GOT_IP` or after the DHCP guard expires.
- [ ] Build the application to catch ESP32 integration errors.

### Task 3: Add Gateway Half-Open Detection

- [ ] Add one-packet asynchronous gateway probes with a 30-second interval and one-second timeout.
- [ ] Ignore failures until one probe has succeeded for the current IP lease.
- [ ] Count three consecutive failures after that baseline before forcing station recovery.
- [ ] Ignore callbacks from a previous lease and treat ping setup failures as diagnostics only.
- [ ] Reset gateway-monitor enforcement on disconnect and new `GOT_IP`.
- [ ] Re-run host tests and the firmware build.

### Task 4: Prepare And Verify Release 1.15.13

- [ ] Bump `platformio.ini`, README, and web installer manifest versions.
- [ ] Add `version.txt` so the embedded ESP-IDF app descriptor reports exactly 1.15.13.
- [ ] Run the relevant host test, PlatformIO `buildprog`, and PlatformIO `buildfs` from a clean source state.
- [ ] Inspect the binary version strings, generated ZIP contents, checksums, and `git diff --check`.
- [ ] Self-review the complete diff and confirm the unrelated bytecode file remains untouched.
- [ ] Commit and push `main`.

### Task 5: Publish And Communicate

- [ ] Create GitHub release 1.15.13 with the generated OTA ZIP and detailed release notes.
- [ ] Verify the release tag, target commit, asset name, and published checksum.
- [ ] Post a detailed issue #21 reply in André's established style, explaining both failure modes and investigation limits.
- [ ] State clearly that physical bridge testing was not possible because André is on holiday, and ask the reporter to test the release.
- [ ] Verify the issue comment URL and public release URL.

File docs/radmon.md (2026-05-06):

# Radmon.org Publishing

Use this guide to connect the RadPro WiFi Bridge to [radmon.org](https://radmon.org), including the station setup and bridge configuration.

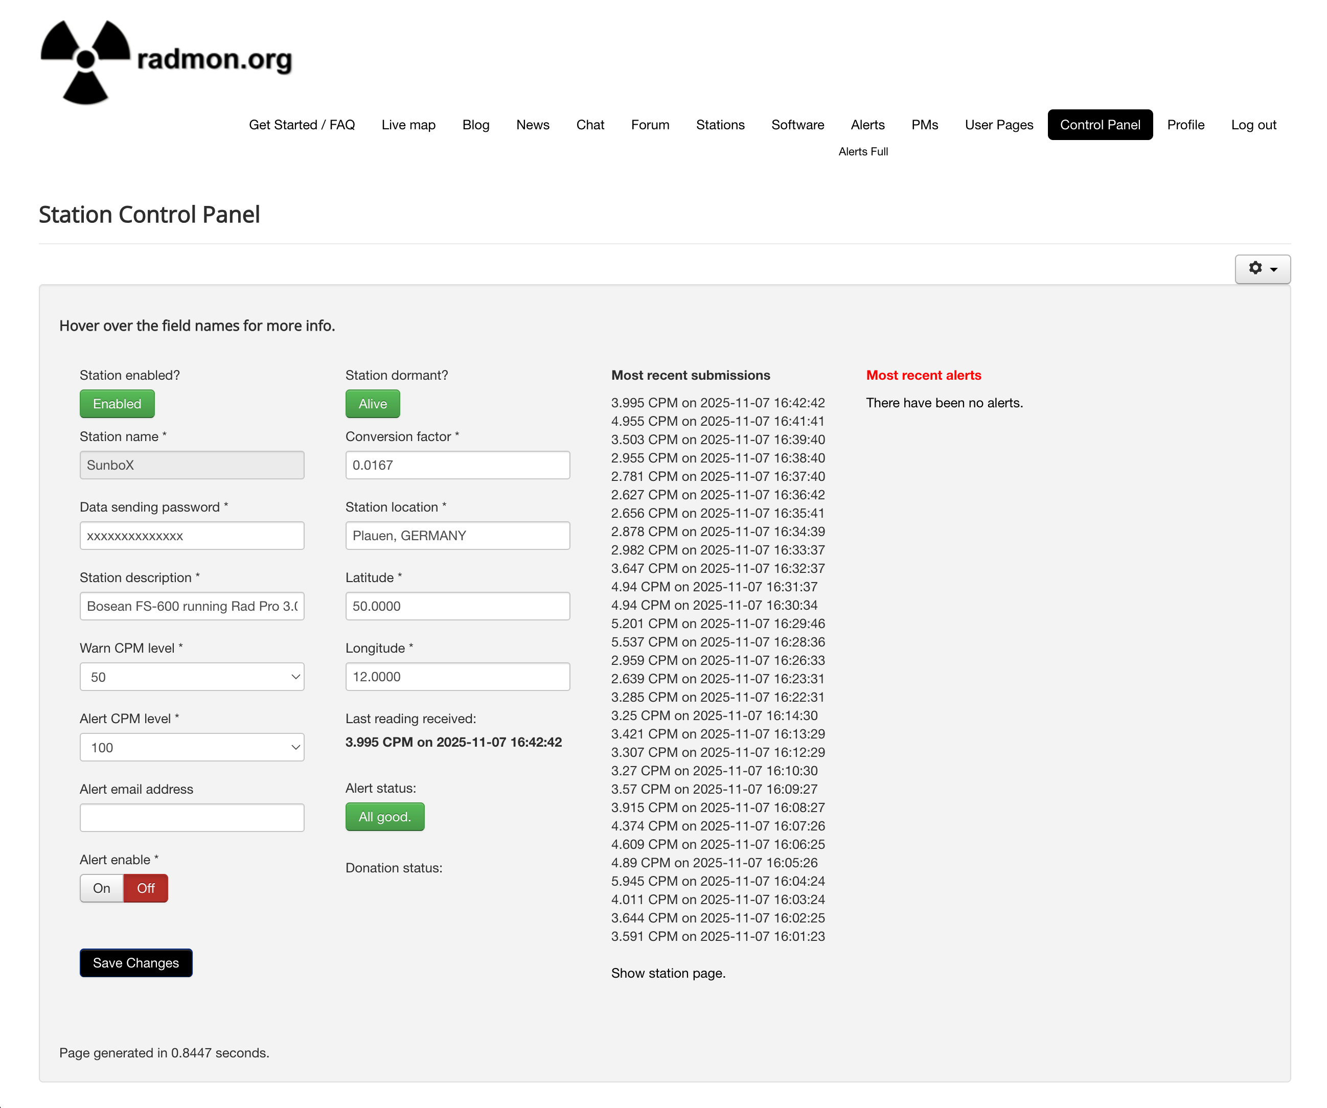
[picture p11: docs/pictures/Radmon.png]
Radmon station dashboard with RadPro WiFi Bridge data


## 1. Prepare Your Radmon Station

1. Create an account on radmon.org and log into the **Station Control Panel**.
2. Under **Station Settings**:
   - Choose a **Station Name** and location.
   - Set the **Data sending password** – this is the credential you’ll enter in the bridge portal.
   - Specify the **Conversion factor** (µSv/h per CPM). For an unmodified RadPro Geiger counter the default is roughly `0.0167`. Adjust if you have a calibration.
3. Note your **Username** and the chosen **Data sending password**.

## 2. Configure the RadPro WiFi Bridge

1. Open the Wi-Fi portal and select **Configure Radmon**.
2. Tick **Enable Radmon publishing**.
3. Enter:
   - **Radmon Username** – your station username (case sensitive).
   - **Radmon Password** – the *data sending* password from the Radmon control panel.
4. Save. Credentials are written to NVS and take effect immediately.
5. After saving, the settings page shows a direct link to the public station page on radmon.org.

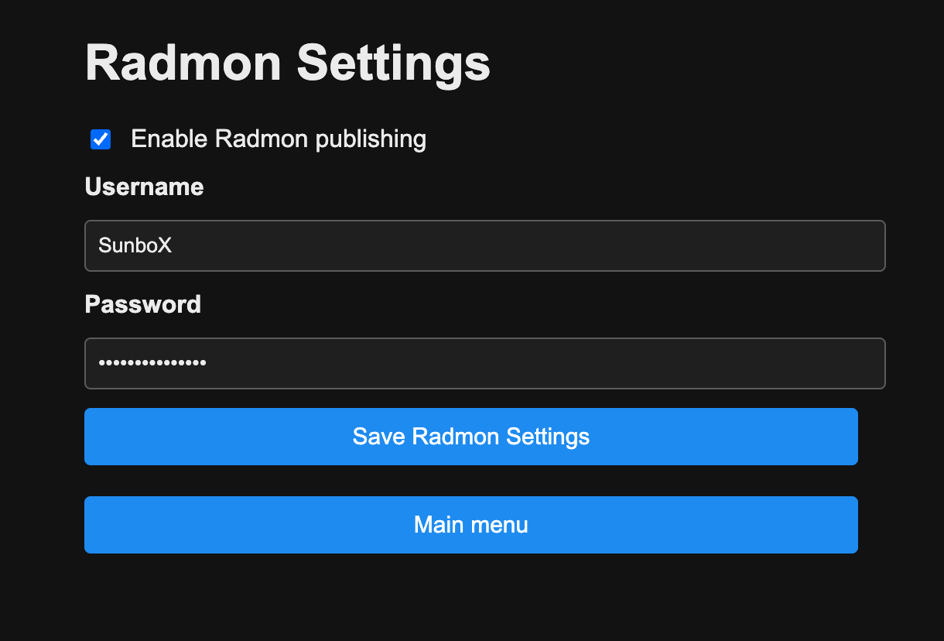
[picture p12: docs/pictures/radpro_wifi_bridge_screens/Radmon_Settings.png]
Portal Radmon configuration page


### Publishing Behaviour

- The bridge sends `GET https://radmon.org/radmon.php?function=submit&user=<user>&password=<pass>&value=<CPM>&unit=CPM`.
- When dose rate is available it adds `value2=<µSv/h>&unit2=uSv/h`.
- Requests are spaced at least 60 seconds apart to stay within radmon.org rate limits.
- Successful posts clear the retry timer; failures trigger retries with a one-minute back-off.

## 3. Verify Data

- Watch the bridge serial console for entries like `Radmon: GET /radmon.php?...`.
- On radmon.org, open **Latest Data** or your station page to confirm CPM/µSv/h values are arriving.

## Troubleshooting

| Symptom | Fix |
| --- | --- |
| HTTP 401/403 response | Username/password mismatch – re-enter the *data sending* password (not your website login password). |
| HTTP 5xx response | Temporary radmon outage; the bridge will retry automatically after 60 s. |
| No data on station page | Ensure you let the tube run long enough for both CPM & dose readings; check the conversion factor matches your hardware. |

Once configured, the bridge handles all scheduling—no cron jobs or scripts required. Leave the feature disabled if you are not using radmon.org; the firmware will skip all HTTP requests until you enable it. \ No newline at end of file

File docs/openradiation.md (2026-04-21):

# OpenRadiation Publishing

This guide explains how to connect the RadPro WiFi Bridge to [OpenRadiation](https://www.openradiation.org/) and what each OpenRadiation-specific field in the bridge portal does.

## 1. Get Your OpenRadiation Credentials

1. Create or log into your OpenRadiation account.
2. Request an API key for measurement uploads from the OpenRadiation team if you do not already have one.
3. Keep your OpenRadiation **user ID / pseudo** and **plain-text account password** ready. The bridge includes both fields in each submitted measurement so OpenRadiation can associate future measurements with your account.
4. Decide whether you want to provide a dedicated **Apparatus ID**:
   - Leave it blank to let the bridge reuse the connected detector's device ID automatically.
   - Fill it in if OpenRadiation assigned you a specific apparatus identifier for this station.

## 2. Configure the RadPro WiFi Bridge

1. Open the Wi-Fi portal and go to **Configure OpenRadiation**.
2. Tick **Enable OpenRadiation publishing**.
3. Enter:
   - **OpenRadiation Apparatus ID (optional)** - leave empty to use the detector device ID.
   - **OpenRadiation API Key** - the upload key issued by OpenRadiation.
   - **OpenRadiation user ID / pseudo** - the account identifier to associate with submitted measurements.
   - **OpenRadiation user password** - required by the OpenRadiation API when `userId` is sent.
   - **Latitude / Longitude** - station coordinates in decimal degrees.
   - **Altitude (m)** - station elevation in meters above sea level.
   - **Position accuracy (m)** - accuracy of the configured position.
   - **Measurement environment** - one of `countryside`, `city`, `inside`, `ontheroad`, or `plane`.
   - **Measurement height above ground (m)** - sensor height relative to the local ground level.
4. Save the form. Settings are written to NVS immediately.

If the API key, user ID, user password, latitude, or longitude is missing, the bridge will not publish to OpenRadiation.

## Security Notes

- The bridge stores the OpenRadiation API key, user ID, and user password in on-device NVS. They are not hard-coded in the repository.
- The OpenRadiation dry-run preview redacts the API key and password before returning the payload.
- Serial logs never print the raw OpenRadiation API key or password.
- Treat `/backup.json` exports as sensitive because they include saved service credentials.

## 3. Publishing Behaviour

- The bridge submits dose-rate measurements to `https://submit.openradiation.net/measurements`.
- Each publish includes the configured location metadata, bridge-generated timestamps, software version, report UUID, and the configured OpenRadiation `userId` / `userPwd`.
- `reportContext` is fixed to `routine` for normal fixed-beacon submissions.
- The OpenRadiation page in the portal exposes:
  - a link to the public OpenRadiation map for the configured coordinates
  - a **Preview dry-run payload** link that builds a local redacted payload and never submits it
  - a **Latest measurement** page that looks up the last successful report UUID via the OpenRadiation request API
- The bridge derives `altitudeAccuracy` from the configured position accuracy and includes `measurementEnvironment`, `measurementHeight`, `endTime`, and `hitsNumber` when valid data is available.

## 4. Local Dry-Run Preview

- Open `/openradiation` in the bridge portal.
- Click **Preview dry-run payload (redacted, no submission)**.
- The bridge builds a representative OpenRadiation measurement payload locally, redacts `apiKey` and `userPwd`, and returns the preview as JSON.
- The dry-run preview never calls the OpenRadiation submit API.

## 5. Verify Data

- Watch the serial console for `OpenRadiation: POST dose=...` messages.
- Open the bridge portal page at `/openradiation` and use the map link to confirm the station position.
- After the first successful upload, open `/openradiation/latest` to inspect the most recently published measurement.

## Troubleshooting

| Symptom | Fix |
| --- | --- |
| `OpenRadiation: missing required OpenRadiation credentials: ...` | Save the API key, OpenRadiation user ID, and OpenRadiation user password on the `/openradiation` page. |
| `OpenRadiation: latitude/longitude not configured; skipping publish.` | Add valid coordinates in the portal and save again. |
| HTTP 4xx response from OpenRadiation | Re-check the API key, apparatus ID, and required location fields. |
| `/openradiation/dry-run` returns an error JSON payload | The preview could not build a valid payload. Re-check the required OpenRadiation credentials first. |
| `/openradiation/latest` shows a 404 page | No successful OpenRadiation publish has been recorded yet. Wait for the first accepted upload. |
| Map link is missing on the portal page | Add latitude and longitude first; the map link is only shown when both are configured. |

Disable the feature if you do not use OpenRadiation; the firmware will not make OpenRadiation requests until the toggle is enabled and the required fields are present.

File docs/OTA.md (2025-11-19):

# RadPro WiFi Bridge OTA Updates

This firmware adds a dedicated **Firmware Update** page in the Wi-Fi portal so you can keep your bridge up to date without a USB cable. Two workflows are available and both are driven from `/ota` in the captive portal.

## 1. Update via Internet

1. Connect the bridge to Wi-Fi and open the configuration portal.
2. Navigate to **Firmware Update** and review the *Current* versus *Latest* versions. The bridge fetches the latest `manifest.json` from `https://sunbox.github.io/radpro-wifi-bridge/web-install/` (GitHub Pages) whenever the page is opened.
3. Press **Download & Install Latest Build**. The ESP32 starts a background task that
   - downloads the manifest,
   - retrieves every `.bin` listed in the manifest (`bootloader.bin`, `partitions.bin`, `radpro-wifi-bridge.bin`, `littlefs.bin`, …), and
   - flashes each part at the offset defined in the manifest via `esp_flash_write()`.
4. While the download runs the progress indicator shows the active part and bytes written. You can abort with **Cancel Update**.
5. After every part is written the bridge remounts LittleFS, marks the OTA as successful, and reboots automatically so the new firmware (and LittleFS content) takes effect.

> **Tip:** Keep the portal window open during the update so you can see status messages (HTTP downloads, flash progress, or errors such as Wi-Fi disconnects).

## 2. Manual ZIP Upload

If the bridge cannot reach GitHub Pages you can upload the firmware bundle yourself.

1. Build or download a bundle that contains:
   - `manifest.json` (same layout as the web installer) and
   - every file referenced in `manifest.builds[0].parts` (e.g. `firmware/latest/bootloader.bin`, `firmware/latest/partitions.bin`, `firmware/latest/radpro-wifi-bridge.bin`, `firmware/latest/littlefs.bin`).
2. Pack those files into a ZIP archive while preserving the relative paths listed in the manifest.
3. Open **Firmware Update** in the Wi-Fi portal, select the ZIP, and click **Upload Firmware ZIP**.
4. The browser unpacks the archive with JSZip, streams `manifest.json` to the ESP32, and uploads every binary in 16 KB base64 chunks over HTTPS (`/ota/upload/*` endpoints). Progress and errors are shown on the page.
5. When all parts are written the bridge finishes the OTA session, remounts LittleFS, and reboots automatically.

### ZIP Bundle Checklist

| Required file | Description |
|---|---|
| `manifest.json` | Defines the version and flash layout |
| `firmware/latest/bootloader.bin` | Bootloader image |
| `firmware/latest/partitions.bin` | Partition table |
| `firmware/latest/radpro-wifi-bridge.bin` | Main firmware image |
| `firmware/latest/littlefs.bin` | Web-portal/LittleFS image |

Add additional parts if the manifest references them. The uploader verifies that every path in the manifest exists inside the ZIP before flashing.

## Safety Notes

- OTA operations unmount LittleFS while `littlefs.bin` is written. Static pages might fail to load during the update—this is expected. The filesystem is automatically remounted once the OTA finishes or is aborted.
- All flash writes use offsets taken from the manifest, so keep the file paths and offsets in sync whenever you publish a new bundle.
- If anything goes wrong you can press **Cancel Update** to abort, remount LittleFS, and return the bridge to its previous state.

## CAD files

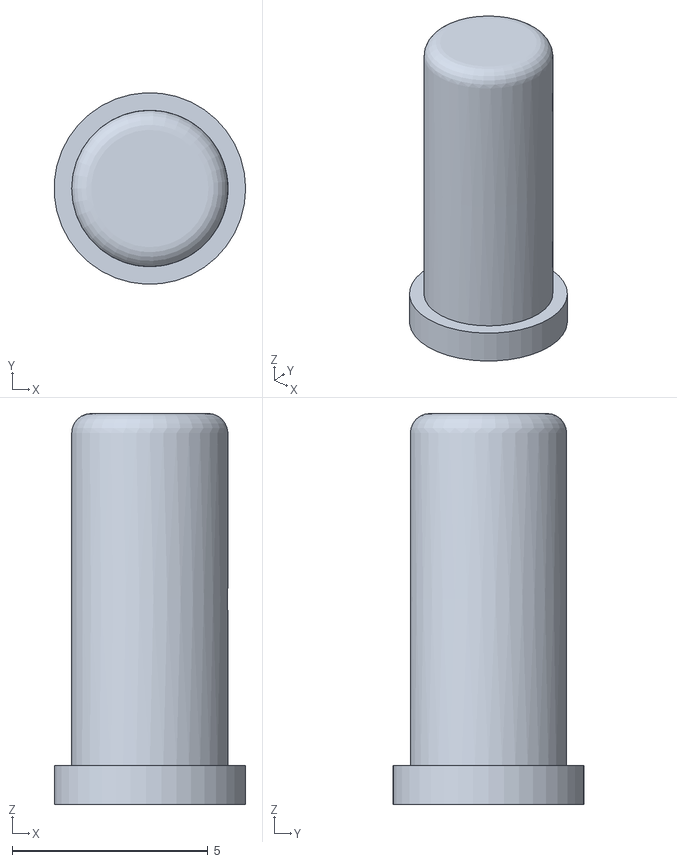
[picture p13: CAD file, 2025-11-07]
docs/case/ESP32-S3 Button 2x.stl
4.89 x 4.90 x 10.0

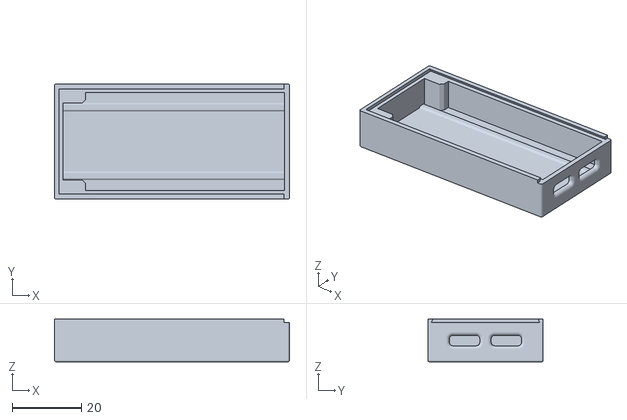
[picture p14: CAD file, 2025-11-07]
docs/case/ESP32-S3 Bottom.stl
67.8 x 33.3 x 12.4

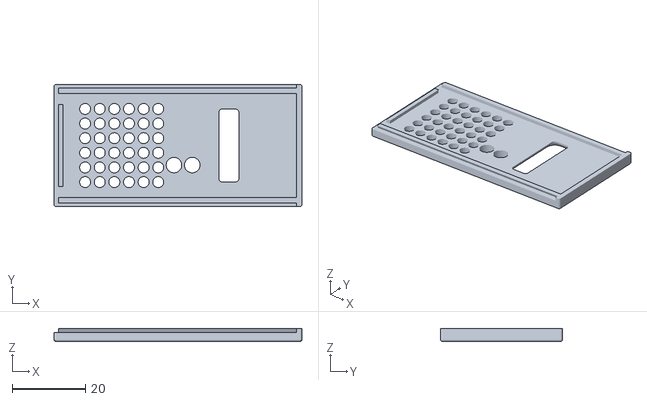
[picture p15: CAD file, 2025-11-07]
docs/case/ESP32-S3 Top.stl
67.8 x 33.3 x 3.50

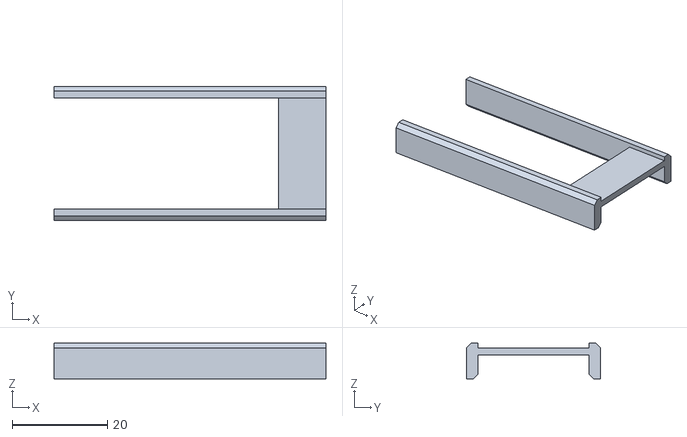
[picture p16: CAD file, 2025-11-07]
docs/case/ESP32-S3 Insert.stl
57.2 x 28.2 x 7.50

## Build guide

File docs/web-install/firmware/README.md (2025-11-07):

# Firmware bundle placeholder

Files in this directory are published to GitHub Pages and consumed by the ESP Web Tools installer.

After every successful PlatformIO build, the helper `tools/copy_firmware.py` mirrors the generated artefacts into `docs/web-install/firmware/latest/` with the correct filenames:

- `.pio/build/esp32-s3-devkitc-1/bootloader.bin` → `docs/web-install/firmware/latest/bootloader.bin`
- `.pio/build/esp32-s3-devkitc-1/partitions.bin` → `docs/web-install/firmware/latest/partitions.bin`
- `.pio/build/esp32-s3-devkitc-1/firmware.bin` → `docs/web-install/firmware/latest/radpro-wifi-bridge.bin`

If you build outside of PlatformIO or need to republish manually, make sure the filenames and offsets continue to match the entries in `docs/web-install/manifest.json`. Update the manifest `version` field whenever you cut a new firmware release.

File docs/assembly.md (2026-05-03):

# RadPro WiFi Bridge Assembly (ESP32-S3)

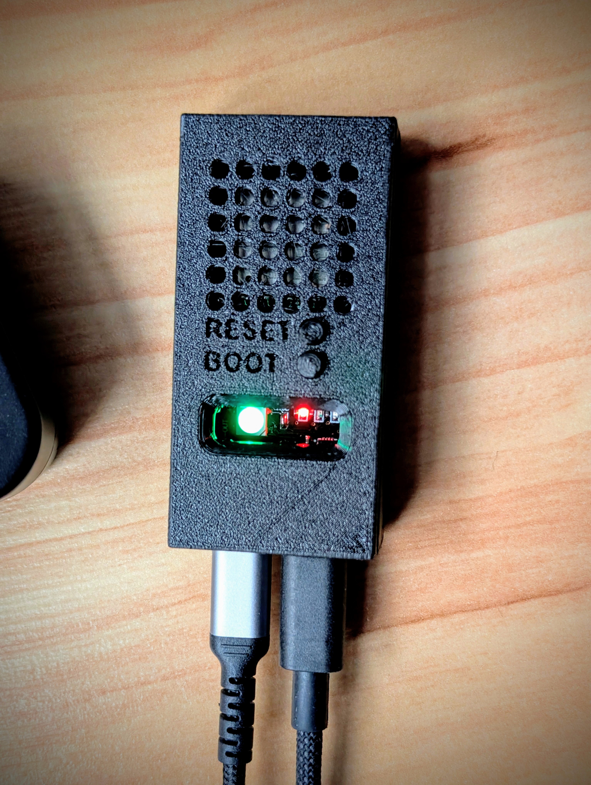
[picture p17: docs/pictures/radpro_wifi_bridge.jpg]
ESP32-S3 DevKitC with USB cables and RGB status LED


The RadPro WiFi Bridge is built around an ESP32‑S3 DevKitC‑1 board running the RadPro WiFi Bridge firmware. The currently recommended variant is `ESP32-S3-DevKitC-1-N16R8`, while the older `N16R8V` remains compatible. Acting as the gateway, it hosts a RadPro-enabled Geiger counter over the USB Type‑C OTG port, translates the USB/Serial data stream, and forwards readings via Wi‑Fi to MQTT and cloud publishers while the WS2812 RGB LED provides status feedback. The default firmware layout expects `16 MB` flash; PSRAM is helpful headroom but not currently required by the source tree.

## Hardware Overview

- **Recommended board:** `ESP32-S3-DevKitC-1-N16R8` (16 MB Flash, 8 MB PSRAM). `N16R8V` is also compatible.
- **Minimum default-build requirement:** `16 MB` flash, USB OTG host capability, and routing/jumpers equivalent to the DevKitC board shown below.
- **Ports:** Two USB‑C connectors are strongly recommended — one OTG port for the detector and one power/debug port.
- **Indicators:** The on-board WS2812 on `GPIO48` is used for status/error pulses, but the current firmware does not require PSRAM.

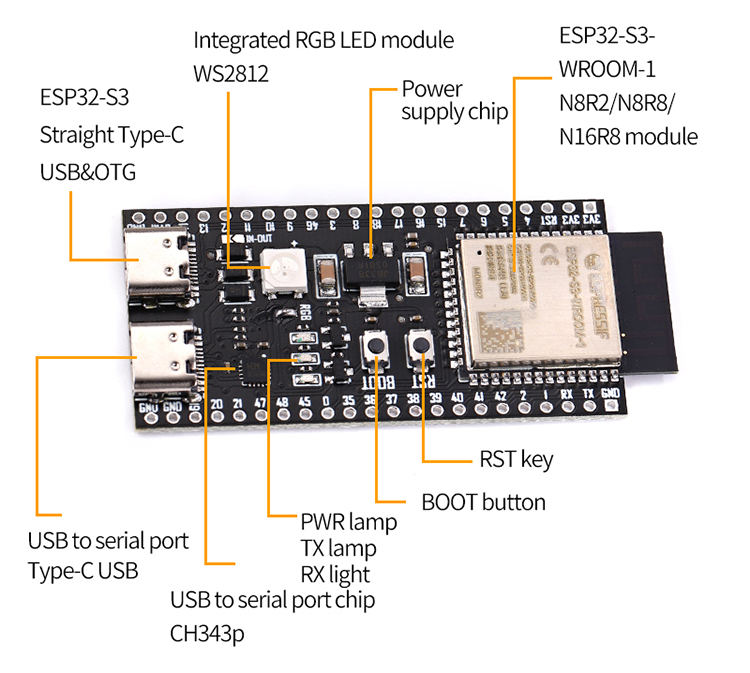
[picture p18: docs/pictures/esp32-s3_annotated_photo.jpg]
Annotated ESP32-S3 board highlighting USB ports, RGB LED, and solder bridges


## Assembly Checklist

To enable USB host mode and the WS2812 LED you must close three solder jumpers on the DevKitC. Use a fine tip iron, plenty of flux, and verify continuity with a multimeter before powering the board. If you are evaluating a different ESP32-S3 board, first compare it against [board-requirements.md](board-requirements.md). If you can’t solder the bridges yourself, check the nearest makerspace or FabLab—community workshops often have the right tools and volunteers who can help. Useful directories:

- [FabLabs.io](https://www.fablabs.io/labs) – official Fab Lab network map (list + JSON export).
- [Hackerspaces.org](https://wiki.hackerspaces.org/List_of_Hacker_Spaces) – global hacker/maker space directory.
- [MapComplete “Hackerspaces & Makerspaces”](https://mapcomplete.osm.be/hackerspaces.html) – OpenStreetMap-based map maintained by the community.
- [Make Magazin (Germany)](https://www.make.de/makerspaces) – German-language makerspace overview (submit your space via make.de).
- [Makers United – Sachsen](https://makers-united.de/makerspaces/) – regional map covering Saxony (handy for Vogtland & surroundings).
- [MapAll.Space](https://mapall.space/) – aggregates SpaceAPI, FabLabs, hackerspaces.org into a single heatmap.
- [CyberLab Makerspace Map](https://www.cyberlab.de/makerspace-map) – curated list of German makerspaces accessible to startups.

### 1. Top-side bridges (RGB + USB data)

- **RGB LED bridge:** Routes GPIO48 to the on-board WS2812 so the LED can mirror bridge diagnostics.  
- **IN/OUT bridge:** Connects the USB D+/D− lines to the OTG controller so the ESP32-S3 can host the RadPro-enabled detector.

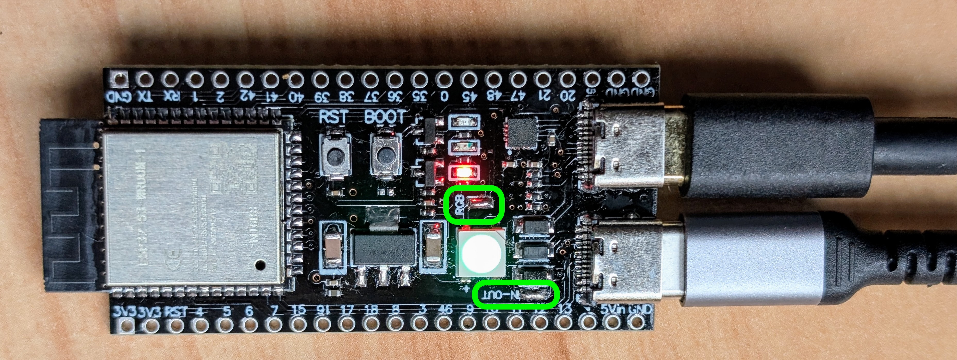
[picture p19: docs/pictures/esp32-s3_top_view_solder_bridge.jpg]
Top view with highlighted solder pads for RGB and IN/OUT jumpers


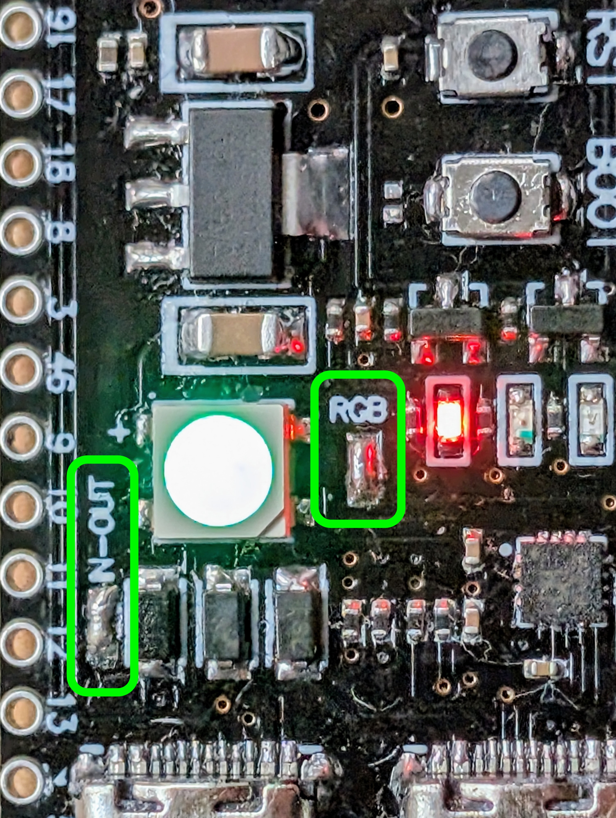
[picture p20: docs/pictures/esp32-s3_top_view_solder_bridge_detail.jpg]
Close-up of completed top-side solder bridges


### 2. Bottom-side bridge (USB-OTG power)

- Close the “USB-OTG” jumper on the underside to power the device connected to the OTG port and allow VBUS sensing.

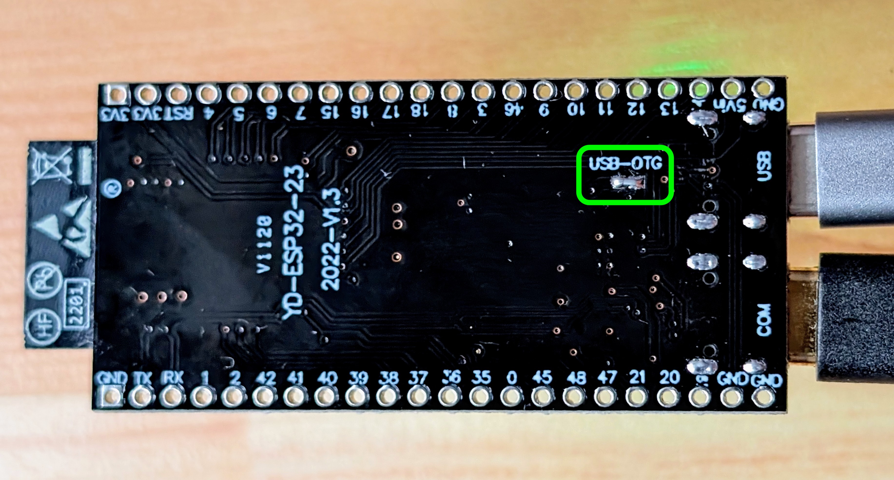
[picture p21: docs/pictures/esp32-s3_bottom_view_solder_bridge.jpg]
Bottom view showing USB-OTG jumper location


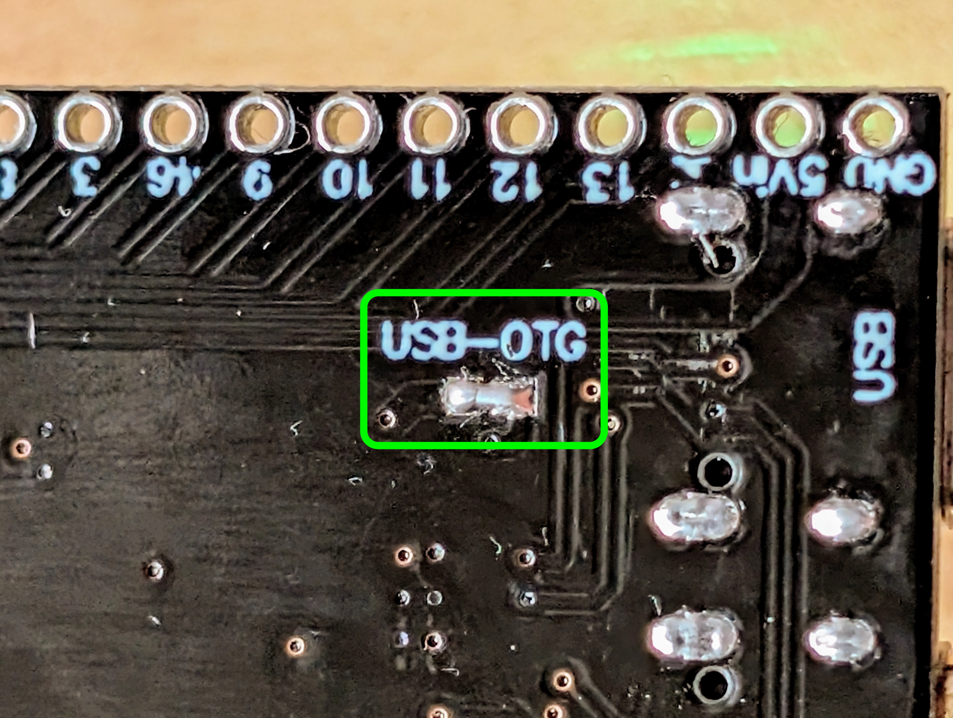
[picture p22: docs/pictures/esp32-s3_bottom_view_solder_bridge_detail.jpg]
Macro photo of the USB-OTG jumper after soldering


After soldering, connect the board via the debug USB‑C port and flash the firmware with the RadPro Web Installer or, if you prefer a local workflow, using PlatformIO (`pio run -t upload`). The OTG port should enumerate the connected Geiger counter automatically once the device is powered.

## 3D-Printed Case

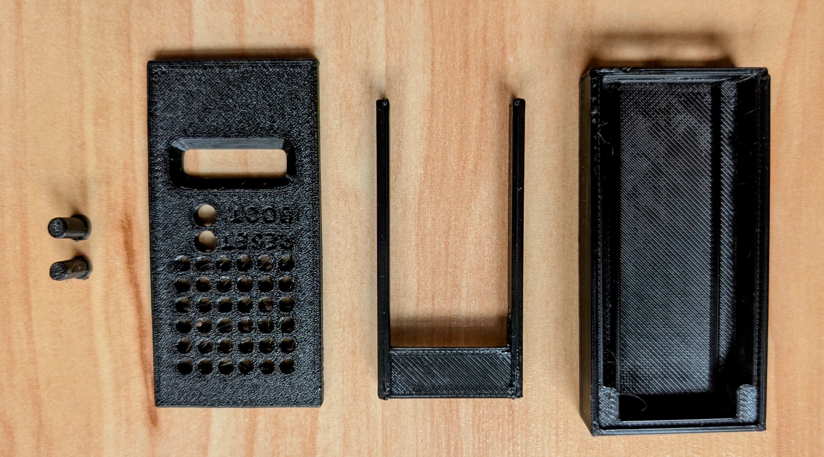
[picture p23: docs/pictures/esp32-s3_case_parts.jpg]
Exploded view of the 3D printed case parts


- Source: [Teraflop on Printables](https://www.printables.com/@Teraflop)  
- Print in PETG or ABS for better heat tolerance. PLA also works if the unit remains indoors.  
- Recommended settings: 0.2 mm layer height, ≥20 % infill, and supports for the USB cut-outs.  
- Seat the DevKitC snugly in the case rails (no screws needed).

## Final Assembly & Connection

RadPro WiFi Bridge connected to a RadPro-enabled Geiger counter

1. Plug the RadPro-enabled Geiger counter into the OTG USB‑C port.  
2. Power the board via the second USB‑C port or through the 5 V header.  
3. Watch the RGB LED: steady green indicates a ready detector, cyan indicates Wi-Fi is joined but the detector is not ready yet, and amber blinking means a communication or telemetry alarm needs attention.
4. Access the Wi-Fi portal (`radpro.local`) to configure MQTT, Radmon, OpenRadiation, and future publishers such as GammaSense/uRADMonitor once available.  

Keep the case vents unobstructed. The RadPro WiFi Bridge is now ready to forward dose-rate measurements to the configured cloud services.

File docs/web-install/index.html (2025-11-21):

# RadPro WiFi Bridge Firmware Installer

Flash the latest RadPro WiFi Bridge firmware to an ESP32-S3 directly from your browser. Connect the board via USB, press the button below, and follow the prompts.

## Supported hardware

The bundled firmware targets the ESP32-S3 DevKitC-1 (16 MB flash) that powers the RadPro WiFi Bridge. Make sure the board is in USB bootloader mode (hold BOOT while tapping RST) before starting the flash process if the device is not automatically detected.

Powered by ESP Web Tools (https://esphome.github.io/esp-web-tools/). Source available on GitHub (https://github.com/esphome/esp-web-tools).

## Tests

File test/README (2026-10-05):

Host and portal tests

Install the PlatformIO project dependencies first (pio pkg install). Then run
the standalone C++17 and Node.js tests from the repository root:

    python3 tools/run_host_tests.py

Requires Python 3, a C++17 compiler, Node.js, and ArduinoJson in the project's
.pio/libdeps/esp32-s3-devkitc-1 directory. No physical bridge is needed or flashed.
Use --cxx or --node to select a compiler or Node.js executable. On macOS,
--sdk can select an SDK compatible
with the installed compiler/linker.

To run just the metrics regression tests:

    python3 tools/run_host_tests.py --filter device_info_prometheus

To also parse the generated responses with an installed official promtool:

    python3 tools/run_host_tests.py --promtool /path/to/promtool

The Prometheus tests compile the actual DeviceInfoPage and DeviceInfoStore,
with host shims only for Arduino, FreeRTOS, WiFiManager/WebServer and LittleFS.
They cover empty readings at boot, USB disconnect, cleared measurements,
independently missing values, real zero readings, numeric precision, escaping
of every label, and UTF-8. The optional promtool checks parse ten captured
responses. Test binaries, logs and responses are written under build/host-tests.

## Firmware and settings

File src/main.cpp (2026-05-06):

// SPDX-FileCopyrightText: 2026 André Fiedler
//
// SPDX-License-Identifier: GPL-3.0-or-later

#include <Arduino.h>
#include "UsbCdcHost.h"
#include "esp_log.h"
#include "esp_system.h"
#include "esp_ota_ops.h"
#if defined(__has_include)
#if __has_include(<esp_app_desc.h>)
#include <esp_app_desc.h>
#define HAS_ESP_APP_DESC 1
#endif
#endif
#include <cstring>
#include <utility>
#include <vector>
#include <WiFi.h>
#include <LittleFS.h>
#include "freertos/FreeRTOS.h"
#include "freertos/task.h"
#include "DeviceManager.h"
#include "AppConfig/AppConfig.h"
#include "ConfigPortal/WiFiPortalService.h"
#include "Led/LedController.h"
#include "Mqtt/MqttPublisher.h"
#include "OpenSenseMap/OpenSenseMapPublisher.h"
#include "GmcMap/GmcMapPublisher.h"
#include "Radmon/RadmonPublisher.h"
#include "OpenRadiation/OpenRadiationPublisher.h"
#include "Safecast/SafecastPublisher.h"
#include "BridgeDiagnostics.h"
#include "PeripheralStarter.h"
#include "Time/TimeSync.h"
#include "DeviceHealth/DeviceActivityMonitor.h"
#include "DeviceInfo/DeviceInfoStore.h"
#include "Ota/OtaUpdateService.h"
#include "FileSystem/BridgeFileSystem.h"
#include "Logging/DebugLogStream.h"
#include "Publishing/PublisherHealth.h"
#include "Runtime/CooperativePump.h"
#include "UsbRecoveryPolicy.h"

#ifndef BRIDGE_FIRMWARE_VERSION
#define BRIDGE_FIRMWARE_VERSION "0.0.0"
#endif

// =========================
// Board / LED definitions
// =========================
#ifndef RGB_BUILTIN
#define RGB_BUILTIN 48 // ESP32-S3 DevKitC-1 onboard WS2812 pin
#endif

// Prefer the CP210x/UART "second USB port" for debug when USB-CDC is on
#if defined(ARDUINO_USB_CDC_ON_BOOT) && (ARDUINO_USB_CDC_ON_BOOT == 1)
#define DBG_SERIAL Serial0
#else
#define DBG_SERIAL Serial
#endif

static DebugLogStream debugSerial(DBG_SERIAL);
#define DBG debugSerial

// =========================
// Startup configuration
// =========================
#define INITIAL_STARTUP_DELAY_MS 0
#define ALLOW_EARLY_START true

// Program state
static bool isRunning = false;
static unsigned long startupDelayMs = INITIAL_STARTUP_DELAY_MS;
static unsigned long startupStartTime = 0;
// Forward declarations
static void handleStartupLogic();
static void runMainLogic();
static void serviceCooperativeTasksDuringNetworkWait();
static const char *commandTypeName(DeviceManager::CommandType type);
static const char *ledModeName(LedMode mode);
static const char *deviceActivityFaultName(DeviceActivityFault fault);
static void updateDeviceErrorState();
static void handleDeviceActivityTransition(DeviceActivityFault previousFault, DeviceActivityFault currentFault);
static void clearPendingMeasurementPublishers();

// =========================
// USB Host wrapper
// =========================
static UsbCdcHost usb;
static DeviceManager device_manager(usb);
static const std::vector<std::pair<uint16_t, uint16_t>> kSupportedUsbVidPid = {
    {0x1A86, 0x7523}, // CH340/341 (Bosean FS-600)
    {0x1A86, 0x7522}, // Alternate CH340 PID sometimes reported
    {0x1A86, 0x5523}, // CH341 variant
    {0x1A86, 0x55D4}, // CH9102F (Fnirsi GC01)
    {0x1A86, 0x55D3}  // CH9102X (Fnirsi GC01 alt)
};

static LedController ledController;
static BridgeDiagnostics diagnostics(DBG, ledController);
static DeviceInfoStore deviceInfoStore;
static bool lastDeviceReadyLogged = false;

static AppConfig appConfig;
static AppConfigStore configStore;
static PublisherHealth openSenseMapHealth;
static PublisherHealth gmcMapHealth;
static PublisherHealth radmonHealth;
static PublisherHealth openRadiationHealth;
static PublisherHealth safecastHealth;
static WiFiPortalService portalService(appConfig, configStore, deviceInfoStore, DBG, ledController, openSenseMapHealth, gmcMapHealth, radmonHealth, openRadiationHealth, safecastHealth);
static MqttPublisher mqttPublisher(appConfig, DBG, ledController);
static OpenSenseMapPublisher openSenseMapPublisher(appConfig, DBG, BRIDGE_FIRMWARE_VERSION, openSenseMapHealth);
static GmcMapPublisher gmcMapPublisher(appConfig, DBG, BRIDGE_FIRMWARE_VERSION, gmcMapHealth);
static RadmonPublisher radmonPublisher(appConfig, DBG, BRIDGE_FIRMWARE_VERSION, radmonHealth);
static OpenRadiationPublisher openRadiationPublisher(appConfig, deviceInfoStore, DBG, BRIDGE_FIRMWARE_VERSION, openRadiationHealth);
static SafecastPublisher safecastPublisher(appConfig, DBG, BRIDGE_FIRMWARE_VERSION, safecastHealth);
static TimeSync timeSync(DBG);
static bool deviceReady = false;
static bool deviceError = false;
static bool commandError = false;
static bool mqttError = false;
static bool updateInProgress = false;
static unsigned long usbDisconnectedSinceMs = 0;
static unsigned long lastUsbRestartAttemptMs = 0;
static PeripheralStarter peripheralStarter(device_manager, usb, mqttPublisher, openSenseMapPublisher, gmcMapPublisher, radmonPublisher, ledController, DBG, ALLOW_EARLY_START, BRIDGE_FIRMWARE_VERSION);
static LedMode lastLoggedMode = LedMode::Booting;
static DeviceActivityMonitor deviceActivityMonitor;

// =========================
// Arduino setup / loop
// =========================
void setup()
{
    // Bring up both Serial endpoints to be safe
    Serial.begin(115200);
    DBG.begin(115200);
    delay(300);

    // Confirm current app as valid to cancel any pending rollback.
    esp_ota_mark_app_valid_cancel_rollback();

    DBG.println("Initializing RadPro WiFi Bridge…");

    if (!BridgeFileSystem::mount(DBG, "setup-initial", true))
    {
        DBG.println("[LittleFS] Initial mount failed; portal assets unavailable.");
    }
    else
    {
        DBG.print("[LittleFS] Portal menu present: ");
        DBG.println(LittleFS.exists("/portal/menu.html") ? "yes" : "no");
        DBG.print("[LittleFS] MQTT page present: ");
        DBG.println(LittleFS.exists("/portal/mqtt.html") ? "yes" : "no");
    }

    deviceInfoStore.setBridgeFirmware(BRIDGE_FIRMWARE_VERSION);
    const esp_partition_t *running = esp_ota_get_running_partition();
    const esp_partition_t *boot = esp_ota_get_boot_partition();
    if (running && boot)
    {
        DBG.print("Partition (running): label=");
        DBG.print(running->label);
        DBG.print(" addr=0x");
        DBG.print(running->address, HEX);
        DBG.print(" size=");
        DBG.println(running->size);

        DBG.print("Partition (boot): label=");
        DBG.print(boot->label);
        DBG.print(" addr=0x");
        DBG.print(boot->address, HEX);
        DBG.print(" size=");
        DBG.println(boot->size);
    }
#ifdef HAS_ESP_APP_DESC
    if (const esp_app_desc_t *desc = esp_app_get_description())
    {
        DBG.print("App description: ");
        DBG.print(desc->project_name);
        DBG.print(" v");
        DBG.print(desc->version);
        DBG.print(" built ");
        DBG.print(desc->date);
        DBG.print(" ");
        DBG.println(desc->time);
    }
#endif

    esp_reset_reason_t resetReason = esp_reset_reason();
    if (resetReason == ESP_RST_BROWNOUT)
    {
        ledController.activateFault(FaultCode::PowerBrownout);
    }
    else if (resetReason == ESP_RST_TASK_WDT || resetReason == ESP_RST_WDT)
    {
        ledController.activateFault(FaultCode::WatchdogReset);
    }

    ledController.begin();
    ledController.setMode(LedMode::Booting);
    ledController.update();

    diagnostics.initialize();
    CooperativePump::setCallback(serviceCooperativeTasksDuringNetworkWait);

    // Record start time for non-blocking startup delay
    startupStartTime = millis();

    device_manager.setLineHandler([&](const String &line) { diagnostics.handleLine(line); });
    device_manager.setRawHandler([&](const uint8_t *data, size_t len) { diagnostics.handleRaw(data, len); });
    usb.setDebugSink(&DBG);
    device_manager.setCommandResultHandler([&](DeviceManager::CommandType type, const String &value, bool success) {
        bool transient = (type == DeviceManager::CommandType::TubePulseCount ||
                          type == DeviceManager::CommandType::TubeRate ||
                          type == DeviceManager::CommandType::DevicePower ||
                          type == DeviceManager::CommandType::DeviceBatteryVoltage ||
                          type == DeviceManager::CommandType::DeviceBatteryPercent ||
                          (type == DeviceManager::CommandType::DeviceId && !deviceReady));
        if (!success)
        {
            DeviceActivityFault previousActivityFault = deviceActivityMonitor.fault();
            DeviceActivityFault currentActivityFault = deviceActivityMonitor.onCommandResult(type, value, false, millis());
            handleDeviceActivityTransition(previousActivityFault, currentActivityFault);
            if (!transient)
            {
                DBG.print("Device command failed: ");
                DBG.print(commandTypeName(type));
                DBG.print(" (");
                DBG.print(static_cast<int>(type));
                DBG.println(")");
                commandError = true;
                if (type == DeviceManager::CommandType::DeviceId)
                {
                    deviceReady = false;
                    DBG.println("DeviceReady cleared after DeviceId failure.");
                }
                ledController.triggerPulse(LedPulse::MqttFailure, 250);
                if (type == DeviceManager::CommandType::DeviceId)
                    ledController.activateFault(FaultCode::DeviceIdTimeout);
                else
                    ledController.activateFault(FaultCode::CommandTimeout);
            }
            updateDeviceErrorState();
            return;
        }

        commandError = false;
        DeviceActivityFault previousActivityFault = deviceActivityMonitor.fault();
        DeviceActivityFault currentActivityFault = deviceActivityMonitor.onCommandResult(type, value, true, millis());
        handleDeviceActivityTransition(previousActivityFault, currentActivityFault);
        updateDeviceErrorState();

        if (type == DeviceManager::CommandType::DeviceId)
        {
            deviceReady = value.length() > 0;
            if (deviceReady)
            {
                ledController.clearFault(FaultCode::DeviceIdTimeout);
                if (!lastDeviceReadyLogged)
                {
                    DBG.println("DeviceReady set after DeviceId response.");
                }
            }
        }

        if (type == DeviceManager::CommandType::DeviceSensitivity)
        {
            float sens = value.toFloat();
            if (sens > 0.0f)
                ledController.clearFault(FaultCode::MissingSensitivity);
            else
                ledController.activateFault(FaultCode::MissingSensitivity);
        }

        if (type == DeviceManager::CommandType::TubeDoseRate)
        {
            if (!device_manager.hasSensitivity())
                ledController.activateFault(FaultCode::MissingSensitivity);
            else
                ledController.clearFault(FaultCode::MissingSensitivity);
        }

        ledController.clearFault(FaultCode::CommandTimeout);

        const bool suppressTelemetry = deviceActivityMonitor.shouldSuppressTelemetry(type);
        if (!suppressTelemetry)
        {
            deviceInfoStore.update(type, value);
            mqttPublisher.onCommandResult(type, value);
            openSenseMapPublisher.onCommandResult(type, value);
            gmcMapPublisher.onCommandResult(type, value);
            radmonPublisher.onCommandResult(type, value);
            openRadiationPublisher.onCommandResult(type, value);
            safecastPublisher.onCommandResult(type, value);
        }
    });

    if (!configStore.load(appConfig))
    {
        DBG.println("Preferences read failed; keeping defaults.");
        ledController.activateFault(FaultCode::NvsLoadFailure);
    }
    else
    {
        ledController.clearFault(FaultCode::NvsLoadFailure);
    }

    portalService.begin();
    portalService.setSafecastPublisher(safecastPublisher);
    openRadiationPublisher.begin();
    safecastPublisher.begin();
    portalService.setOtaStartCallback([&]()
                                      { OtaUpdateService::EnterUpdateMode(device_manager, usb, mqttPublisher, openSenseMapPublisher, gmcMapPublisher, radmonPublisher, safecastPublisher, updateInProgress); });
    timeSync.loop(WiFi.status() == WL_CONNECTED);
    peripheralStarter.startIfNeeded(WiFi.status() == WL_CONNECTED, timeSync.synced(), kSupportedUsbVidPid);
    mqttPublisher.setPublishCallback([&](bool success)
                                     {
        if (success)
        {
            mqttError = false;
            ledController.triggerPulse(LedPulse::MqttSuccess, 150);
            ledController.clearFault(FaultCode::MqttConnectionReset);
        }
        else
        {
            mqttError = false;
        } });

    WiFi.mode(WIFI_STA);
    WiFi.setHostname(appConfig.deviceName.c_str());

    if (!portalService.connect(false))
    {
        DBG.println("Auto-connect or portal timed out; starting configuration portal.");
        portalService.connect(true);
    }
    timeSync.loop(WiFi.status() == WL_CONNECTED);
    mqttPublisher.updateConfig();
    openSenseMapPublisher.updateConfig();
    gmcMapPublisher.updateConfig();
    radmonPublisher.updateConfig();
    openRadiationPublisher.updateConfig();
    safecastPublisher.updateConfig();
    portalService.maintain();
    diagnostics.updateLedStatus(isRunning, deviceError, mqttError, deviceReady);
    LedMode currentMode = ledController.currentModeForDebug();
    if (currentMode != lastLoggedMode)
    {
        DBG.print("LED mode -> ");
        DBG.println(ledModeName(currentMode));
        lastLoggedMode = currentMode;
    }
    ledController.update();
}

void loop()
{
    const bool wifiConnected = WiFi.status() == WL_CONNECTED;
    timeSync.loop(wifiConnected);
    peripheralStarter.startIfNeeded(wifiConnected, timeSync.synced(), kSupportedUsbVidPid);

    if (!isRunning)
    {
        handleStartupLogic();
    }
    else
    {
        runMainLogic();
    }

    if (!updateInProgress && peripheralStarter.started())
    {
        device_manager.loop();
    }
    portalService.syncIfRequested();
    portalService.maintain();
    portalService.process();
    if (!updateInProgress && peripheralStarter.started())
    {
        mqttPublisher.updateConfig();
        mqttPublisher.loop();
        openSenseMapPublisher.updateConfig();
        openSenseMapPublisher.loop();
        gmcMapPublisher.updateConfig();
        gmcMapPublisher.loop();
        radmonPublisher.updateConfig();
        radmonPublisher.loop();
        openRadiationPublisher.updateConfig();
        openRadiationPublisher.loop();
        safecastPublisher.updateConfig();
        safecastPublisher.loop();
    }

    const bool usbConnected = usb.isConnected();
    if (!usbConnected)
    {
        const unsigned long now = millis();
        if (usbDisconnectedSinceMs == 0)
        {
            usbDisconnectedSinceMs = now;
            DeviceActivityFault previousActivityFault = deviceActivityMonitor.fault();
            deviceActivityMonitor.reset();
            handleDeviceActivityTransition(previousActivityFault, deviceActivityMonitor.fault());
            commandError = false;
            updateDeviceErrorState();
            deviceInfoStore.clearLiveData();
            openSenseMapPublisher.clearPendingData();
            gmcMapPublisher.clearPendingData();
            radmonPublisher.clearPendingData();
            openRadiationPublisher.clearPendingData();
            safecastPublisher.clearPendingData();
        }

        if (deviceReady)
        {
            DBG.println("DeviceReady cleared: USB disconnected.");
        }
        deviceReady = false;
        lastDeviceReadyLogged = false;

        if (!updateInProgress &&
            peripheralStarter.started() &&
            wifiConnected &&
            UsbRecoveryPolicy::shouldRestart(now,
                                             usbDisconnectedSinceMs,
                                             lastUsbRestartAttemptMs,
                                             usb.hasObservedDevice(),
                                             usb.restartRunsInBackground()))
        {
            DBG.println("USB disconnected too long; restarting USB host.");
            lastUsbRestartAttemptMs = now;
            if (!usb.requestRestart())
            {
                DBG.println("USB host restart request failed.");
            }
            usbDisconnectedSinceMs = millis();
        }
    }
    else if (deviceReady)
    {
        usbDisconnectedSinceMs = 0;
        lastDeviceReadyLogged = true;
    }
    else
    {
        usbDisconnectedSinceMs = 0;
    }
    if (usbConnected && peripheralStarter.started())
    {
        DeviceActivityFault previousActivityFault = deviceActivityMonitor.fault();
        DeviceActivityFault currentActivityFault = deviceActivityMonitor.evaluate(millis());
        handleDeviceActivityTransition(previousActivityFault, currentActivityFault);
        updateDeviceErrorState();
    }
    diagnostics.updateLedStatus(isRunning, deviceError, mqttError, deviceReady);
    ledController.update();

    // Keep loop snappy; USB host runs in its own tasks
    delay(5);
}

// =========================
// Startup state machine
// =========================
static void handleStartupLogic()
{
    if (!peripheralStarter.started())
    {
        ledController.setMode(LedMode::WaitingForStart);
        return;
    }

    if (!isRunning)
        ledController.setMode(LedMode::WaitingForStart);

    // 1) Timer elapsed?
    if (millis() - startupStartTime >= startupDelayMs)
    {
        isRunning = true;
    }

    // 2) User commands on DBG (e.g., CP210x UART)
    if (DBG.available() > 0)
    {
        String command = DBG.readStringUntil('\n');
        command.trim();

        if (command.startsWith("delay "))
        {
            long newDelay = command.substring(6).toInt();
            if (newDelay > 0)
            {
                startupDelayMs = (unsigned long)newDelay;
                startupStartTime = millis(); // reset timer
                DBG.print("Startup delay updated to: ");
                DBG.print(startupDelayMs);
                DBG.println(" ms");
            }
        }
        else if (command.equalsIgnoreCase("raw on"))
        {
            device_manager.setRawLogging(true);
            DBG.println("USB raw logging enabled.");
        }
        else if (command.equalsIgnoreCase("raw off"))
        {
            device_manager.setRawLogging(false);
            DBG.println("USB raw logging disabled.");
        }
        else if (command.equalsIgnoreCase("raw toggle"))
        {
            device_manager.toggleRawLogging();
            DBG.print("USB raw logging toggled ");
            DBG.println(device_manager.rawLoggingEnabled() ? "ON." : "OFF.");
        }
        else if (command.equalsIgnoreCase("usb debug on"))
        {
            diagnostics.setUsbDebugEnabled(true);
        }
        else if (command.equalsIgnoreCase("usb debug off"))
        {
            diagnostics.setUsbDebugEnabled(false);
        }
        else if (command.equalsIgnoreCase("usb debug toggle"))
        {
            diagnostics.toggleUsbDebug();
        }
        else if (ALLOW_EARLY_START && command.length() > 0)
        {
            isRunning = true;
            DBG.println("Early start triggered by user!");
        }
    }

    // 3) If starting now, announce and switch LED to a short "go" blink
    if (isRunning)
    {
        DBG.println("Starting RadPro WiFi Bridge…");
        device_manager.start();
        portalService.enableStatusLogging();
        ledController.triggerPulse(LedPulse::MqttSuccess, 200);
        return;
    }

    // Periodic countdown message once per second
    static unsigned long lastCountdownTime = 0;
    if (millis() - lastCountdownTime >= 1000)
    {
        lastCountdownTime = millis();
        unsigned long remaining = (startupDelayMs - (millis() - startupStartTime)) / 1000;
        DBG.print("Starting in ");
        DBG.print(remaining);
        DBG.println(" seconds…");
    }
}

// =========================
// Main application tasks
// =========================
static void runMainLogic()
{
    // Poll rad-pro statistics according to configured interval
    static unsigned long lastStatsRequest = 0;
    unsigned long now = millis();
    uint32_t interval = appConfig.readIntervalMs;
    if (interval < kMinReadIntervalMs)
        interval = kMinReadIntervalMs;
    uint32_t stalePulseTimeoutMs = DeviceActivityMonitor::kDefaultStalePulseTimeoutMs;
    if (interval <= UINT32_MAX / 3 && interval * 3 > stalePulseTimeoutMs)
        stalePulseTimeoutMs = interval * 3;
    deviceActivityMonitor.setStalePulseTimeoutMs(stalePulseTimeoutMs);
    if (now - lastStatsRequest >= interval)
    {
        lastStatsRequest = now;
        device_manager.requestStats();
    }
}

static void serviceCooperativeTasksDuringNetworkWait()
{
    portalService.process();
    diagnostics.updateLedStatus(isRunning, deviceError, mqttError, deviceReady);
    ledController.update();
    delay(10);
    yield();
}

static void updateDeviceErrorState()
{
    deviceError = commandError || deviceActivityMonitor.hasFault();
}

static void clearPendingMeasurementPublishers()
{
    openSenseMapPublisher.clearPendingData();
    gmcMapPublisher.clearPendingData();
    radmonPublisher.clearPendingData();
    openRadiationPublisher.clearPendingData();
}

static void handleDeviceActivityTransition(DeviceActivityFault previousFault, DeviceActivityFault currentFault)
{
    if (previousFault == currentFault)
        return;

    if (currentFault == DeviceActivityFault::None)
    {
        DBG.println("Device telemetry alarm cleared.");
        return;
    }

    DBG.print("Device telemetry alarm: ");
    DBG.println(deviceActivityFaultName(currentFault));
    deviceInfoStore.clearMeasurements();
    clearPendingMeasurementPublishers();
}
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

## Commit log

2025-08-17 Initializes PlatformIO project structure
    Sets up the initial project structure for the RadPro WiFi Bridge, including:
    - PlatformIO configuration file (`platformio.ini`) for ESP32-S3 development.
    - VS Code configuration files for enhanced development experience (.vscode/).
    - Initial source code file (`src/main.cpp`) with basic startup and loop logic.
    - README files for `include/` and `lib/` directories, explaining their intended use.
    - .gitignore file to exclude build artifacts and IDE-specific files.
    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
2025-08-17 Initializes RadPro WiFi Bridge project
    Sets up a basic project structure for the RadPro WiFi Bridge, including:
    - PlatformIO configuration for ESP32-S3 DevKitC-1 (N16R8) with TinyUSB host enabled and UART debug.
    - Initial Arduino sketch with a non-blocking startup sequence, USB host enumeration, and RGB LED heartbeat.
    - A README with project overview, features, quick start guide, and roadmap.
    This commit provides a functional baseline for further development.
2025-10-29 Adds DeviceManager for USB device handling
    Introduces a DeviceManager class to handle USB device connection, disconnection, and device ID retrieval.
    This change centralizes USB device management, handling device connection events, sending commands to retrieve device IDs, and managing retry logic for failed requests. It also adds raw USB traffic logging for debugging purposes.
    [main.cpp]
2025-10-29 Adds DeviceManager class
    Introduces a DeviceManager class to handle communication with USB devices.
    This includes managing device connection/disconnection, sending commands,
    handling responses, and logging raw USB traffic. It also implements a
    command queue to ensure requests are processed in order and retries
    failed requests for device ID retrieval. Verbose logging of the host
    message queue can now be toggled at the CLI. The CLI now has `random`
    and `datalog` commands. Radpro device statistics are now requested
    periodically by the host.
    [main.cpp]
2025-10-30 Adds WiFi configuration portal
    Introduces a WiFi configuration portal based on WiFiManager,
    allowing users to configure WiFi and MQTT settings through
    a captive portal or a web UI.
    Persists configuration in NVS.
    Adds device configuration and management via WiFi.
2025-10-30 Enables Wi-Fi status logging on startup
    Adds a mechanism to enable or disable Wi-Fi status logging.
    This allows the device to log connection status and IP address
    upon successful Wi-Fi connection. The logging is enabled
    during startup, ensuring that connection details are captured.
    Also prevents duplicate logging of IP addresses.
    [main.cpp]
2025-10-30 Adds MQTT publishing functionality
    Implements MQTT publishing of device data and status.
    This allows the device to send sensor readings,
    device status, and other relevant information to an
    MQTT broker for remote monitoring and control.
    Adds a new `MqttPublisher` class to handle MQTT
    connection management, topic construction, and
    message publishing. Integrates with the
    `DeviceManager` to publish command results.
    [main.cpp]
2025-10-30 Enhances device telemetry and config portal
    Adds MQTT publishing, Home Assistant discovery, and LED status indications.
    This commit introduces several enhancements to the device, including:
    - Implements MQTT publishing of device telemetry data with configurable topics and retain settings.
    - Adds Home Assistant discovery payloads for automatic sensor creation.
    - Introduces an RGB LED state machine to indicate device status (booting, connecting, ready, error) and events (MQTT success/failure).
    - Integrates a "Restart Device" button into the configuration portal.
    - Improves Wi-Fi reconnection logic.
    - Adds basic battery percentage calculation based on voltage.
    These changes improve the overa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
    [partitions.csv]
2025-10-30 Adds LED fault code reporting
    Implements a fault reporting system using the status LED.
    This commit introduces specific blink patterns to indicate various error conditions such as Wi-Fi authentication failures, MQTT connection issues, NVS load/write failures, and USB communication errors.
    The system displays the lowest-numbered active fault code, enabling easier diagnosis of device issues without requiring serial log analysis.
    [main.cpp]
2025-10-30 Enables ESP Web Tools installer via GitHub Pages
    Adds a web-based firmware installer using ESP Web Tools, hosted via GitHub Pages.
    This allows users to flash the device firmware directly from a browser
    without needing to install the toolchain. The landing page pulls
    firmware from a dedicated `docs/firmware/latest/` directory, which is
    automatically refreshed after each successful build using a PlatformIO
    post-build hook.
    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
2025-10-31 Adds OpenSenseMap publishing support
    Adds support for publishing sensor data to OpenSenseMap.
    This allows users to contribute their radiation data to the
    openSenseMap project.
    Includes configuration options in the web portal for enabling
    OpenSenseMap, setting the box ID, API key, and sensor IDs.
    Publishes tube rate and dose rate values together in a single
    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
2025-11-01 Adds GMCMap publishing feature
    Implements GMCMap publishing functionality, allowing the device to send measurements to GMCMap.
    Adds configuration options to the web portal for enabling GMCMap and setting the account and device IDs.
    Publishes tube rate and dose rate data to GMCMap via HTTP GET requests.
2025-11-01 Adds Radmon.org publishing support
    Implements support for publishing radiation data to Radmon.org.
    This includes:
    - Adds RadmonPublisher class to handle data submission.
    - Adds configuration parameters for Radmon.org credentials to the web portal.
    - Adds Radmon settings to the AppConfig.
    The RadmonPublisher sends tube rate and dose rate to radmon.org
    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
2025-11-04 Updates firmware version to 1.3.0
    Updates the RadPro WiFi Bridge firmware version to 1.3.0.
    This change ensures the correct version is reported in the user-agent
    header for outbound requests to Radmon, OpenSenseMap, and GMCMap,
    as well as in the web UI and MQTT topic.
    Adds diagnostic features, including LED status updates and USB debug log level control.
    [main.cpp]
2025-11-05 Adds OpenRadiation data publishing
    Implements support for publishing radiation data to the OpenRadiation platform.
    This change introduces:
    - New configuration options for OpenRadiation device ID, API key, and location data (latitude, longitude, altitude, accuracy) in the configuration portal.
    - A new OpenRadiationPublisher class to handle the data formatting and submission to the OpenRadiation API.
    - Integration of the OpenRadiation publisher into the main application loop and device manager.
2025-11-07 Adds assembly guide and cloud service docs
    Introduces a detailed assembly guide for the RadPro WiFi Bridge, covering hardware setup, soldering jumpers, and case assembly.
    Provides documentation for integrating with GMCMap, MQTT/Home Assistant, OpenSenseMap, and Radmon, including setup instructions and troubleshooting tips.
    Moves firmware binaries and manifest to a new "web-install" directory.
    [ESP32-S3 Bottom.stl, ESP32-S3 Button 2x.stl, ESP32-S3 Insert.stl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]
2025-11-07 Improves README clarity and flow
    Refactors the README to improve the clarity of the quick start instructions and web installer information. Reorders and rewords steps for a smoother user experience.
2025-11-07 Simplifies PlatformIO instructions
    Removes the "Quick Start" heading, streamlining the PlatformIO installation and first boot instructions for better readability and flow.
2025-11-07 Relocates serial console commands section
    Moves the serial console commands section in the README to a more logical position after the Wi-Fi Configuration Portal section, improving readability and flow.
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2025-11-07 Prevents Wi-Fi power save during portal
    Disables Wi-Fi power saving while the captive portal is active and
    restores the previous power saving mode when the portal is closed.
    This prevents connectivity issues that can occur when the Wi-Fi
    adapter enters a low-power state while the user is interacting
    with the portal.
2025-11-07 Updates documentation for flash size
    Updates the documentation to reflect the correct flash size (16 MB) for the ESP32-S3 DevKitC-1 used in the RadPro WiFi Bridge.
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2025-11-09 Improves UI and device info update frequency
    Addresses potential layout issues in the configuration portal by adding `box-sizing: border-box` to input elements.
    Enhances user experience by increasing the frequency of device info updates on the device info page.
    Fixes a typo in the "Live measurements" section title on the device info page.
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2025-11-14 Refactors config portal to use LittleFS
    Refactors the configuration portal to serve HTML and CSS assets from the LittleFS filesystem.
    Adds new HTML pages for device info, bridge info, MQTT configuration, OpenSenseMap configuration, Radmon configuration, GMCMap configuration, and configuration backup/restore.
    Also introduces a Prettier configuration file.
    [partitions.csv]
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2025-11-14 Increases flash size to 16MB
    Updates flash size to 16MB to accommodate larger application and filesystem.
    The partition table is adjusted to reflect the new flash size and the littlefs partition is increased. The web install manifest is updated with the correct offset for the littlefs partition.
    [partitions.csv]
2025-11-18 Adds FNIRSI GC-01 support, improves USB handling
    Adds support for FNIRSI GC-01 Geiger counters (CH9102F/X USB VID/PIDs).
    Improves USB device handling:
    - Implements device allowlisting for faster device selection
    - Adds logging for USB events and device enumeration
    - Adds diagnostics for USB connectivity
    - Improves USB error handling and recovery
    - Skips notification EP with invalid bInterval
    Reduces initial device ID request delay and retry delay
    [main.cpp]
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2025-11-18 Clarifies RadPro compatibility
    Updates the README to clarify Rad Pro compatibility beyond Bosean FS-600, indicating it's tested with other "Rad Pro class" devices.
    This improves clarity for users with similar devices, such as the FNIRSI GC-01, and encourages them to report compatibility issues.
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2025-11-19 Enables over-the-air (OTA) firmware updates
    Adds a new "Firmware Update" page to the web portal, enabling users to update the device firmware wirelessly.
    Supports two update methods: automatic updates from a remote repository and manual updates via ZIP file upload. Includes status monitoring, progress display, and error handling for a seamless update experience.
2025-11-20 Updates to v1.10.1 and adds OTA updates
    Updates the firmware version to 1.10.1 and implements over-the-air (OTA) update functionality via the web portal. This includes:
    - Updates the manifest to use the new firmware version.
    - Adds OTA update handlers in the configuration portal.
    - Introduces an OTA update service to manage the update process.
    - Pauses device publishers and the USB connection during OTA updates.
    - Increases the stack size to accommodate larger JSON documents.
    - Adds firmware type identification and skipping protected regions during OTA.
    [partitions.csv]
2025-11-21 Updates to v1.10.3 and improves WiFi portal
    Updates the firmware version to 1.10.3.
    Enhances the WiFi configuration portal by:
    - Adding static IP configuration and channel settings.
    - Improving handling of onboarding mode and reconnection attempts to provide a more stable experience.
    - Adding logging for AP client connections/disconnections.
    Introduces a PeripheralStarter class to manage the starting of peripherals based on WiFi connectivity.
    Includes a fix where the config restore would not apply settings until a device reboot.
    [main.cpp]
2025-11-21 Updates firmware to version 1.10.6
    Updates the firmware to version 1.10.6.
    This commit includes updated firmware binaries,
    and updates the manifest and platformio configuration
    to reflect the new version.
    Improves USB device connection reliability by adjusting
    the retry mechanism and logging. It backs off retries to
    avoid spamming the logs, but ensures eventual reconnection.
2025-11-21 Updates firmware to version 1.10.7
    Updates the firmware to version 1.10.7.
    This change includes updated firmware binaries and a
    modified manifest to reflect the new version.
    Additionally, fixes a config restore issue by initiating
    a full restart of the device after configuration, ensuring
    a clean state and proper application of the new settings.
2025-12-02 Updates firmware to 1.11.0 and improves stability
    Updates the bridge firmware to version 1.11.0.
    Adds auto-clearing of USB fault LEDs after a period of inactivity.
    Improves OpenSenseMap publisher robustness with exponential backoff and TLS error handling. Also adds a workaround for an ESP32 mbedTLS quirk related to time sync/wifi stability.
    Attempts level-1 IRQ affinity for USB host installation and falls back to default if it's unavailable.
    Updates fault LED timing to a slower rate.
2025-12-03 Updates bridge firmware to v1.11.1
    Updates the bridge firmware to version 1.11.1.
    This update includes fixes for device ID retrieval timeout,
    LED status updates, and minor UI adjustments.
    Specifically:
    - Updates the firmware version in platformio.ini, README, and manifest.json.
    - Replaces the translated "unknown version" string with a dash in the UI.
    - Reduces the font size of the version value in the UI.
    - Adds device ID retry logic with host restart on initial failure.
    - Clears pending commands on USB disconnect.
    - Adds debug logging for command failures and LED mode transitions.
    [main.cpp]
2025-12-03 Adds NTP time synchronization
    Implements NTP time synchronization to ensure the device has the correct time.
    This is used to ensure the device starts peripherals only when the device has the correct time.
    Fixes FS-5000
    [main.cpp]
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2026-04-21 fix: skip unsupported GC-01 HV metadata probes
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2026-05-06 Add Safecast publishing and USB recovery fixes
    [main.cpp]
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2026-11-05 Add configurable USB recovery watchdog
    Restart after a previously responding detector stops replying, with a five-minute default, portal settings and backup persistence. Suspend recovery during firmware updates and wait for new telemetry after boot to avoid reboot loops.
    Give detectors connected after boot their own opening grace period before USB host recovery can interrupt enumeration.
    Validated with 42 host/portal test programs and a GC-03 cable-disconnect/reconnect test on the bridge.
    Refs #24
2026-11-06 Report MQTT availability and prevent network publishing stalls
    Publish retained online/offline status with a Last Will and attach availability to all discovered entities. Queue USB responses so only the main loop writes MQTT packets, and allow MQTT to be enabled again without changing its connection settings.
    Bound OpenSenseMap connection and TLS waits, service Wi-Fi recovery and MQTT during cooperative response waits, and close completed publisher responses without an unbounded drain.
    Validated with 44 host/portal test programs and connected GC-03 tests for Wi-Fi loss, gateway recovery, MQTT disable/resume, retained availability, Home Assistant state and a silent TLS peer. The separate SY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
2026-11-06 Resynchronize USB replies after command timeouts
    Discard the expired command batch and suspend numeric polling until a matching detector identity reply establishes a new serial-stream boundary. Reject numeric or empty identity responses, block auxiliary requests during recovery, reread calibration, and send only one identity query per attempt.
    Regression tests reproduce the shifted count/rate/voltage sequence and preserve correctly matched high readings. Physical tests on the connected Wi-Fi Bridge and GC-03 held real power and count-rate replies for 13.5 seconds and recovered without rebooting or artificial MQTT spikes.
    Related discussion: https://github.com/Gissio/radpro/discussions/434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
2026-11-06 Avoid stale socket errors resetting HTTP connections
2026-11-14 Release 1.15.20: bound Safecast samples and retain crash logs
